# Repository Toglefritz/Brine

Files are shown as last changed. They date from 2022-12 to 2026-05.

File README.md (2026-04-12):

# Brine

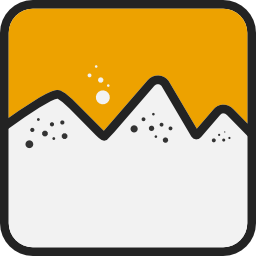
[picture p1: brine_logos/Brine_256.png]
Brine logo


# Hello :wave:

Do you ever forget to refill the salt in your water softener? Yes you do. It is probably a safe
bet to say that everybody who has a water softener in their home forgets to refill the salt from
time to time. That "time to time" might even be several months in row.

The Brine water softener monitor keeps track of the amount of salt remaining in your water softener
and delivers alerts when the level is low. With this tool, you can keep your water softener filled
with salt and working properly, which, in turn, will keep your appliances free of mineral deposits,
your hands and hair well-moisturized, your laundry machine effective, and spots off your dishes.

# Overview 

Brine is an IoT water softener monitor. It tracks the amount of salt remaining in a water softener
and delivers alerts when the level is low, keeping your appliances free of mineral deposits, your
hands and hair well-moisturized, your laundry machine effective, and spots off your dishes.

The project spans hardware, firmware, a mobile companion app, cloud backend services, and a
marketing website.

## Project Status

> **Hardware finalization and pre-manufacturing**
>
> The hardware design is being finalized ahead of final system integration.
> Preparation for first-run manufacturing is underway.

## How It Works

A Brine device mounts inside the lid of a water softener, facing down toward the salt. It uses a
VL53L1X distance sensor to measure the distance from the top of the softener to the salt surface,
then calculates an approximate percentage of salt remaining. The device wakes from deep sleep once
every 24 hours to take a measurement, report it to the cloud, and go back to sleep.

Users set up a Brine device through the companion mobile app using Bluetooth Low Energy. The app
walks through pairing, WiFi provisioning, and account association. Once provisioned, the app
displays a dashboard with salt level, battery level, and device information, and delivers push
notifications when levels are low.

## Repository Structure

| Directory | Description |
|---|---|
| [`brine_app`](brine_app/) | Flutter companion app for iOS, Android, and macOS. Handles device provisioning via BLE and displays device status on a dashboard. |
| [`brine_firmware`](brine_firmware/) | ESP32 firmware built with PlatformIO and the Arduino framework. Manages the distance sensor, battery monitoring, BLE communication, and deep sleep. |
| [`brine_cloud_functions`](brine_cloud_functions/) | Firebase Cloud Functions that form the backend infrastructure. Handles device registration, data ingestion, and push notifications. |
| [`brine_website`](brine_website/) | Flutter web marketing site for the Brine product. |
| [`brine_docs`](brine_docs/) | Project documentation covering OTA updates, power management, provisioning, and security. |
| [`brine_electronics`](brine_electronics/) | PCB designs, Gerber files, prototypes, and reference materials for the Brine hardware. |
| [`brine_cad`](brine_cad/) | 3D models and drawings for the device enclosure (Plasticity, STEP, and STL formats). |
| [`brine_logos`](brine_logos/) | Brand assets and logo files in various formats. |
| [`brine_store_listings`](brine_store_listings/) | App store listing assets including screenshots and feature graphics. |
| [`brine_dev_tui`](brine_dev_tui/) | Terminal UI launcher for starting development tools (firmware flashing, emulator, serial monitor, Flutter app, Firebase emulator). |

## Development Launcher

The project includes a terminal UI for launching the various tools needed during local development.
Instead of remembering individual commands across multiple directories, the launcher provides a
single interface to start everything from one place.

Double-click `brine_dev_tui/Brine Launcher.command` in Finder to build and run it, or from the
terminal:

```sh
cd brine_dev_tui
go build -o brine-launcher .
./brine-launcher
```

See [`brine_dev_tui/README.md`](brine_dev_tui/README.md) for controls and architecture details.

## Technology Overview

- **Firmware**: C++ on ESP32 via PlatformIO / Arduino framework
- **Mobile App**: Flutter (Dart), targeting iOS, Android, and macOS
- **Backend**: Firebase (Cloud Functions, Firestore, Authentication, Cloud Messaging)
- **Website**: Flutter Web, hosted on Firebase Hosting
- **Hardware**: Custom PCB with ESP32 and VL53L1X distance sensor, powered by rechargeable LiPo battery
- **CAD**: Plasticity for enclosure design

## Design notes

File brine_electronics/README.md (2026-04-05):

# Brine

PCB design and hardware reference for the Brine Monitor, an IoT device that monitors the amount of
salt remaining in a water softener.

## Hello :wave:

Do you ever forget to refill the salt in your water softener? Yes you do. It is probably a safe
bet to say that everybody who has a water softener in their home forgets to refill the salt from
time to time. That "time to time" might even be several months in row.

The Brine water softener monitor keeps track of the amount of salt remaining in your water softener
and delivers alerts when the level is low. With this tool, you can keep your water softener filled
with salt and working properly, which, in turn, will keep your appliances free of mineral deposits,
your hands and hair well-moisturized, your laundry machine effective, and spots off your dishes.

## Hardware Overview

The Brine device is a battery-powered sensor board built around a Seeed Studio XIAO ESP32-S3
module. It measures the distance from the top of a water softener to the salt surface using a
VL53L1X time-of-flight distance sensor, then reports that measurement to the cloud over WiFi.

The board includes:

- XIAO ESP32-S3 microcontroller module (WiFi, BLE, and GPIO)
- VL53L1X time-of-flight distance sensor connected over I2C
- Battery power input with a voltage divider for battery level monitoring
- A physical button for entering setup mode and waking from deep sleep
- An RGB LED for status indication during provisioning and operation

The PCB is a two-layer board designed to fit inside a custom enclosure. Enclosure models are
maintained separately in the [`brine_cad`](../brine_cad/) directory.

## KiCAD Project

The active design lives in the `Brine Mainboard/` directory and is a KiCAD 9 project.

### Hierarchical Schematic Structure

The schematic is organized as a set of hierarchical sheets. The root sheet (`Brine.kicad_sch`)
acts as a block diagram of the hardware, showing each functional block and the signals that
connect them. Each block is defined in its own schematic sheet with the full circuit detail for
that subsystem.

| Sheet | File | Description |
|---|---|---|
| Root | `Brine.kicad_sch` | Top-level block diagram showing all subsystems and their interconnections. |
| XIAO ESP32-S3 | `xiao_esp32-s3.kicad_sch` | Microcontroller module pinout and connections to all peripheral blocks. |
| Battery | `brine_battery.kicad_sch` | Battery input and power delivery. |
| Button | `brine_button.kicad_sch` | Physical pushbutton circuit for user interaction and wake-from-sleep. |
| RGB LED | `brine_rgb_led.kicad_sch` | Status LED driven by the microcontroller. |
| Battery Monitor | `brine_battery_monitor.kicad_sch` | Voltage divider circuit for reading battery level on an analog input. |
| Distance Sensor | `brine_distance_sensor.kicad_sch` | VL53L1X time-of-flight sensor with I2C and shutdown control lines. |

The root sheet is the best starting point for understanding how the subsystems relate to each
other. Open it in KiCAD's schematic editor to see the block-level signal flow, then navigate into
individual sheets for component-level detail.

### PCB Layout

The PCB (`Brine.kicad_pcb`) is a two-layer board. A 3D STEP model of the board (`Brine.step`) is
included for use in enclosure design and fit verification.

Production outputs, including Gerbers, BOM, and pick-and-place position files, are generated into
the `production/` subdirectory.

## Directory Structure

| Directory | Description |
|---|---|
| `Brine Mainboard/` | Active KiCAD project containing schematics, PCB layout, production outputs, and the board STEP model. |
| `Libraries/` | Custom KiCAD symbol and footprint libraries for components not available in the default KiCAD libraries (e.g., VL53L1X). |
| `Gerbers/` | Legacy Gerber output directory. Current production files are generated into `Brine Mainboard/production/`. |
| `Archive/` | Previous board revisions and design iterations, including earlier EAGLE-based designs. Kept for reference. |

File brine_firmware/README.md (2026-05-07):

# Brine Device Firmware

This repository contains the firmware for Brine, an IoT device that monitors the amount of salt remaining in a water softener.

# Hello :wave:

Do you ever forget to refill the salt in your water softener? Yes you do. It is probably a safe bet to say that everybody who has a water softener in their home forgets to refill the salt from time to time. That "time to time" might even be several months in row.

The Brine water softener monitor keeps track of the amount of salt remaining in your water softener and delivers alerts when the level is low. With this tool, you can keep your water softener filled with salt and working properly, which, in turn, will keep your appliances free of mineral deposits, your hands and hair well-moisturized, your laundry machine effective, and spots off your dishes.

## Hardware

The Brine device is built around the ESP32, a powerful, versatile microcontroller that provides the WiFi connectivity necessary for the IoT functionality of the device and BLE connectivity necessary for its setup process. The ESP32 was chosen for its combination of processing power, connectivity options, and power efficiency, which is crucial for a battery-powered device.

The primary sensor used by the Brine device is the VL53L1X distance sensor. This sensor measures the distance from the top of the water softener to the level of the salt within the appliance. By comparing this measurement to the known distance when the water softener is empty, the device can calculate an approximate percentage of salt remaining.

For user feedback, the device includes an LED. This LED can display different patterns to indicate the device's status. This system is mainly used during the provisioning process and the LED generally remains off during normal operation so its use does not affect the battery life of the device.

The device is powered by a rechargeable lithium polymer battery. To maximize battery life, the device spends most of its time in a deep sleep state. It wakes up once every 24 hours to measure the salt level, send the data to the backend services, and then returns to the deep sleep state. This power management strategy allows the device to operate for extended periods without requiring a battery change.

The device is designed to be mounted inside the lid of a water softener, facing down towards the salt. This positioning allows the distance sensor to accurately measure the salt level.

## Firmware

The firmware for the Brine device is written using PlatformIO, an open-source ecosystem for IoT development, in conjunction with Visual Studio Code, a powerful and versatile code editor. The Arduino framework is used due to its simplicity, robustness, and the vast amount of resources and libraries available.

The firmware follows a service-oriented architecture, encapsulating different pieces of functionality into their own modules. This design allows for a high degree of modularity and reusability, making the firmware easier to understand, maintain, and extend.

Each service in the firmware is responsible for a specific piece of functionality. For example, there might be a service for managing the distance sensor, another for handling communication with the backend services, and yet another for controlling the RGB LED.

The firmware also includes power management functionality to ensure the device spends most of its time in a deep sleep state, waking up only to perform measurements and communicate with the backend services. This approach maximizes battery life and ensures the device can operate for extended periods without requiring a battery change.

```mermaid
graph LR
    A[main.cpp] --> B[Button Service]
    A --> C[LED Service]
    A --> D[Distance Sensor Service]
    A --> F[Battery Monitor Service]
    B --> G[Button Hardware]
    C --> H[LED Hardware]
    D --> I[Distance Sensor Hardware]
    F --> K[Battery Monitor Hardware]
```

## Getting Started

To start working with the Brine device firmware, follow these steps:

### Setting Up the Development Environment
1. Install [Visual Studio Code](https://code.visualstudio.com/download).
2. Open Visual Studio Code and navigate to the Extensions view (View -> Extensions).
3. Search for and install the PlatformIO IDE extension.

### Adding Libraries
The Brine device firmware uses several libraries. To add them to your project:
1. Open the PlatformIO home page in Visual Studio Code (View -> PlatformIO).
2. Navigate to Libraries.
3. Search for and install the following libraries: (List the libraries used by the project)

### Connecting the Device
1. Connect the Brine device to your development machine using a USB cable.
2. In Visual Studio Code, open the PlatformIO home page.
3. Navigate to Devices to verify that the Brine device is recognized.

### Flashing Firmware
1. Open the Brine device firmware project in Visual Studio Code.
2. Build the project by clicking the checkmark icon in the PlatformIO toolbar.
3. Upload the firmware to the device by clicking the right arrow icon in the PlatformIO toolbar.

After following these steps, your Brine device should be running the latest firmware and ready for use.

## Commenting and Documentation

Doxygen-style comments are used throughout this project for code documentation. This allows for the automatic generation of documentation and ensures that the codebase is easy to understand and maintain.

The following guidelines regarding documentation should be followed while working on this project:

1.  Always document code as it is written. It is much easier to write comments while the code is fresh in your mind and you still have the context in which it was written.
2. Use Doxygen-style comments (`/** ... */` for multi-line comments, `///` for single-line comments).
3.  Document all public APIs. Include a brief description, detailed description, parameters, and return values.
4.  Use `@brief` for a brief description, `@details` for a detailed description, `@param` for parameters, and `@return` for return values.
5.  For classes and structures, document what they represent and how they should be used.
6.  For functions, document what they do, what the parameters are, what value they return, if any, and the purpose for which they were created.

Here is a generic Doxygen comment template for a function:

```
/**
 * @brief Brief description of the function
 * @details Detailed description of the function
 * 
 * @param paramName Description of the parameter
 * @return Description of the return value
 */
void functionName(Type paramName) {
    // function body
}
```

And for a class:

```
/**
 * @brief Brief description of the class
 * @details Detailed description of the class
 */
class ClassName {
    // class body
}
```

## Bluetooth Communication

Brine devices utilize Bluetooth communication for the provisioning process. This technology allows for seamless and efficient communication between client devices, such as the companion Brine mobile app, and Brine IoT devices.

All Brine devices use the same UUID (Universally Unique Identifier) for their primary services. This UUID is a unique string of characters that identifies the services provided by the Brine device. It can be used as a filter by client devices when performing a scan for nearby Brine devices. The UUID for Brine devices is as follows:

> 6272696E-6573-616C-746D-6F6E69746F72

In addition to the primary service UUID, Brine devices also use the same UUID values for their BLE (Bluetooth Low Energy) characteristics. These characteristics are attributes that define the behavior of the Brine device. The UUIDs for these characteristics allow client devices to identify and interact with the correct characteristics on the Brine device.

### Bluetooth API Overview

The Bluetooth API implemented in the IoT device firmware allows for communication with a central device (such as a Flutter app) using a JSON-based protocol. This section provides an overview of the structure of the API, including the format for commands and responses, and details how the firmware processes these communications.

### Command Structure

Commands are received from the central device and are represented as JSON objects. Each command must include a command field specifying the type of command being issued.

**Example Command**

To request the device ID from the IoT device, the following JSON command is sent:

```json
{
    "command": "get_device_id"
}
```

### Response Structure

Responses are sent from the IoT device to the central device in reply to commands. Each response is represented as a JSON object and includes a response field specifying the type of response.

**Success Responses**

A successful response to the get_device_id command will include the device ID:

```json
{
    "response": "device_id",
    "device_id": "vast_teal_elephant"
}
```

**Error Responses**

If an error occurs or an unknown command is received, an error response is sent:

```json
{
    "response": "error",
    "message": "Unknown command"
}
```

## PlatformIO CLI Commands

### Flashing Firmware

Build and upload firmware to the connected device:

```bash
pio run -e seeed_xiao_esp32c3 --target upload
```

Build without uploading (compile check only):

```bash
pio run -e seeed_xiao_esp32c3
```

### Running Tests

Run a specific test suite on hardware:

```bash
pio test -e seeed_xiao_esp32c3 --filter <test_name>
```

For example, to run the GPIO button test:

```bash
pio test -e seeed_xiao_esp32c3 --filter test_GPIOButton
```

Run all tests:

```bash
pio test -e seeed_xiao_esp32c3
```

### Serial Monitor

Open the serial monitor to view debug output:

```bash
pio device monitor
```

### Clean Build

Remove all build artifacts and force a full rebuild:

```bash
pio run -e seeed_xiao_esp32c3 --target clean
```

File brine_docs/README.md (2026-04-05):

# Brine

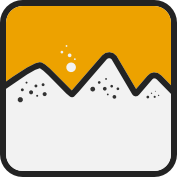
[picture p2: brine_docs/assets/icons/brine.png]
Brine logo


Documentation for the Brine Monitor, an IoT device that monitors the amount of salt remaining
in a water softener.

## Hello :wave:

Do you ever forget to refill the salt in your water softener? Yes you do. It is probably a safe
bet to say that everybody who has a water softener in their home forgets to refill the salt from
time to time. That "time to time" might even be several months in row.

The Brine water softener monitor keeps track of the amount of salt remaining in your water softener
and delivers alerts when the level is low. With this tool, you can keep your water softener filled
with salt and working properly, which, in turn, will keep your appliances free of mineral deposits,
your hands and hair well-moisturized, your laundry machine effective, and spots off your dishes.

## Table of Contents

1. [Power](power/)
    - [battery_monitoring](power/battery_monitoring.md): Describes the voltage divider circuit used to monitor the voltage of the AA batteries that power the Brine device, including resistor selection and safe input levels for the ESP32 analog pin.
    - [deep_sleep_handling](power/deep_sleep_handling.md): Explains how the Brine firmware uses the ESP32's deep sleep mode to conserve battery, including the 24-hour wake cycle, timer and GPIO wakeup sources, and the setup mode triggered by a physical button press.
2. [OTA](ota/)
    - [ota_architecture](ota/ota_architecture.md): Documents the architecture of the over-the-air firmware update system, covering the device, cloud, and mobile components, the update flow sequence, data formats, security layers, and deployment topology.
    - [ota_setup](ota/ota_setup.md): A setup guide for the OTA cloud infrastructure, including Firebase Cloud Function deployment, Firestore collection configuration, Storage rules, firmware version management, and testing procedures.
3. [Provisioning](provisioning/)
    - [provisioning_process](provisioning/provisioning_process.md): Walks through the full provisioning sequence for a new Brine device, from physical button activation and BLE pairing through device association, PSK transfer, WiFi credential exchange, hardware installation, and appliance height configuration.
4. [Security](security/)
    - [hmac_security](security/hmac_security.md): Explains the HMAC-based request signing mechanism used to authenticate data sent from Brine devices to the Firebase backend, including how PSKs are provisioned, how signatures are generated and verified, and how keys can be rotated or revoked.
5. [Cloud](cloud/)
    - [cloud_infrastructure](cloud/cloud_infrastructure.md): Describes the Firebase-based cloud backend, including the Firestore data model, the set of Cloud Functions exposed as HTTP endpoints, authentication and HMAC verification, push notifications, and local development with the Firebase Emulator Suite.

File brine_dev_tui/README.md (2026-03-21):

# Brine Launcher

A terminal UI for launching the development tools used in the Brine project. Instead of memorizing and manually running a collection of terminal commands, this tool provides a single interface to start and stop everything you need for local development.

Built with [Go](https://go.dev), [Bubbletea](https://github.com/charmbracelet/bubbletea), and [Lipgloss](https://github.com/charmbracelet/lipgloss).

## Why This Exists

The Brine project involves multiple systems that need to run simultaneously during development: device firmware, a device emulator, a serial monitor, the Flutter mobile app, and the Firebase emulator suite. Remembering the exact commands for each, and running them in the right order, is tedious and error-prone. This launcher centralizes all of that into a single, navigable interface.

## Available Tools

| Tool | Description |
|---|---|
| Flash Firmware | Build and flash firmware to the device |
| Device Emulator | Start the device emulator for local testing  |
| Serial Monitor | Open serial monitor for device output |
| Flutter App | Launch the Flutter mobile application |
| Firebase Emulator  | Start the Firebase local emulator suite |

## Usage

### Build and Run

```sh
cd brine_dev_tui
go build -o brine-launcher .
./brine-launcher
```

### Controls

| Key | Action |
|---|---|
| `↑` / `k` | Move cursor up |
| `↓` / `j` | Move cursor down |
| `Enter` / `Space` | Toggle selected tool (start/stop) |
| `q` / `Ctrl+C` | Quit |

## Architecture

The application follows the [Elm Architecture](https://guide.elm-lang.org/architecture/) via Bubbletea, which separates concerns into model, update, and view.

```
brine_dev_tui/
├── main.go      Entry point. Initializes and runs the Bubbletea program.
├── model.go     Application state and input handling (Update loop).
├── view.go      Renders the interface from current state (View function).
├── tool.go      Tool type definition and the default tool list.
├── styles.go    All Lipgloss visual styles and color palette.
├── go.mod       Go module and dependencies.
└── go.sum       Dependency checksums.
```

## Dependencies

- [Bubbletea](https://github.com/charmbracelet/bubbletea) — Terminal UI framework based on the Elm Architecture.
- [Lipgloss](https://github.com/charmbracelet/lipgloss) — Styling and layout for terminal rendering.

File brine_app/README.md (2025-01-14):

# Brine

Brine logo

The companion app for the Brine Monitor, an IoT device that monitors the amount of salt remaining
in a water softener.



# Hello :wave:

Do you ever forget to refill the salt in your water softener? Yes you do. It is probably a safe
bet to say that everybody who has a water softener in their home forgets to refill the salt from
time to time. That "time to time" might even be several months in row.

The Brine water softener monitor keeps track of the amount of salt remaining in your water softener
and delivers alerts when the level is low. With this tool, you can keep your water softener filled
with salt and working properly, which, in turn, will keep your appliances free of mineral deposits,
your hands and hair well-moisturized, your laundry machine effective, and spots off your dishes.

# Application Flow

The application has two main workflows. First, the app implements a provisioning process used to
add a Brine device to the user's account. This process consists of communicating with a target
Brine device via Bluetooth Low Energy, connecting that device to a WiFi network, and performing an
API call necessary to associate the Brine device to the user's account.

Second, the app displays information about one or more Brine devices on a user's account on a
"dashboard" screen, which includes the most recently reported salt and battery level for the
device, as well as information about the device itself. The app will facilitate the delivery
of push notifications when the battery and/or salt level on one of the Brine devices for a user
are low.

## Provisioning Flow

The diagram below shows the provisioning flow for a Brine device.

> Some details in this flow are still being implemented and may change over time.

```mermaid
sequenceDiagram
    participant User
    participant MobileApp
    participant BrineDevice
    participant Backend

    User ->> BrineDevice: Press button to initiate device activation
    BrineDevice ->> MobileApp: Start BLE advertising
    MobileApp ->> MobileApp: Scan for BLE devices
    MobileApp ->> BrineDevice: Discover Brine device
    MobileApp ->> BrineDevice: Perform BLE pairing and bonding
    MobileApp ->> BrineDevice: Retrieve device ID
    MobileApp ->> Backend: Send device ID and user ID
    Backend ->> Backend: Associate device with user account
    MobileApp ->> Backend: Request PSK for the Brine device
    Backend ->> MobileApp: Generate and return PSK
    MobileApp ->> BrineDevice: Transfer PSK
    BrineDevice ->> BrineDevice: Save PSK to NVS
    MobileApp ->> BrineDevice: Request WiFi scan results
    BrineDevice ->> BrineDevice: Perform WiFi scan
    BrineDevice ->> MobileApp: Return list of WiFi networks
    User ->> MobileApp: Select WiFi network
    User ->> MobileApp: Provide WiFi credentials
    MobileApp ->> BrineDevice: Send WiFi credentials over BLE
    BrineDevice ->> BrineDevice: Connect to WiFi network
    BrineDevice ->> MobileApp: Report WiFi connection success
    MobileApp ->> User: Notify provisioning completion
```

# Bluetooth API Overview

The Bluetooth API enables communication between the Flutter app and the IoT device using a
JSON-based protocol. This section provides an overview of the structure of the API, including the
format for commands and responses

## Command Structure

Commands are sent from the central device (e.g., a Flutter app) to the IoT peripheral device. Each
command is represented as a JSON object with a command field specifying the type of command.

**Example Command**:

To request the device ID from the IoT device, the following JSON command is used:

```json
{
    "command": "get_device_id"
}
```

## Response Structure

Responses are sent from the IoT peripheral device to the central device in reply to commands. Each response is represented as a JSON object with a response field specifying the type of response.

**Success Responses**

For example, a successful response to the get_device_id command will include the device ID:

```json
{
    "response": "device_id",
    "device_id": "Brine-1234"
}
```

**Error Responses**

If an error occurs or an unknown command is received, an error response is sent:

```json
{
    "response": "error",
    "message": "Unknown command"
}
```

# Firebase Local Emulator Notes

Development can be done against the Firebase local emulator rather than the live Firebase
environment in order to prevent interference with the production environment and to provide a
safe environment for development without billing.

Start the Firebase emulator with the command, `firebase emulators:start`.

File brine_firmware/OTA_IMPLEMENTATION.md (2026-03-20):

# Brine OTA (Over-The-Air) Firmware Update System

## Overview

The Brine device supports Over-The-Air (OTA) firmware updates through two methods:
1. **Cloud-based updates** (Primary method) - Firmware is downloaded from Firebase Storage via WiFi
2. **Bluetooth-based updates** (Backup method) - Firmware is transferred via BLE (future enhancement)

## Architecture

### Cloud Components

#### Firebase Cloud Function: `checkFirmwareUpdate`
- **Endpoint**: `/checkFirmwareUpdate`
- **Method**: POST
- **Purpose**: Checks if a newer firmware version is available for a device

**Request Body**:
```json
{
  "device_id": "device-123",
  "current_version": "1.0.0"
}
```

**Response (Update Available)**:
```json
{
  "update_available": true,
  "latest_version": "1.1.0",
  "download_url": "https://storage.googleapis.com/...",
  "release_notes": "Bug fixes and improvements"
}
```

**Response (No Update)**:
```json
{
  "update_available": false,
  "message": "Current version is up to date.",
  "current_version": "1.0.0",
  "latest_version": "1.0.0"
}
```

#### Firestore Collection: `firmware_versions`

Each firmware version document contains:
```javascript
{
  version: "1.1.0",              // Semantic version string
  version_number: 110,           // Numeric version for sorting (major*100 + minor*10 + patch)
  download_url: "https://...",   // Firebase Storage URL for firmware binary
  release_notes: "...",          // Optional release notes
  active: true,                  // Whether this version should be offered to devices
  created_at: "2025-11-27T...",  // Timestamp
  file_size: 1234567,            // Size in bytes
  checksum: "sha256:..."         // Optional checksum for verification
}
```

### Firmware Components

#### OTAService Class
Located in `lib/OTAService/`

**Key Methods**:
- `checkForUpdate(String &latestVersion, String &downloadUrl)` - Queries cloud for updates
- `performCloudUpdate(const String &downloadUrl)` - Downloads and applies firmware
- `beginBluetoothUpdate(size_t firmwareSize)` - Prepares for BLE update
- `writeBluetoothChunk(const uint8_t *data, size_t len)` - Writes BLE data chunk
- `endBluetoothUpdate()` - Finalizes BLE update
- `getCurrentVersion()` - Returns current firmware version
- `abortUpdate()` - Cancels an in-progress update

#### Firmware Version
Defined in `include/OTAService.h`:
```cpp
#define FIRMWARE_VERSION "1.0.0"
```

**Important**: Update this version string with each firmware release.

## Update Workflow

### Cloud Update Process

1. **Device Wake-Up**
   - Device wakes from deep sleep (timer or button press)
   - Connects to WiFi using saved credentials
   - Calls `_checkAndPerformOTAUpdate()`

2. **Update Check**
   - Device sends current version to `checkFirmwareUpdate` endpoint
   - Cloud function queries Firestore for latest active firmware
   - Compares versions using semantic versioning

3. **Update Download & Installation**
   - If update available, device downloads firmware binary
   - ESP32 Update library writes to OTA partition
   - Progress is logged every 10%
   - LED indicates update in progress

4. **Verification & Reboot**
   - Firmware is verified
   - Device reboots into new firmware
   - On next wake, device reports new version

### Update Trigger Points

The device checks for updates at two key moments:

1. **Periodic Wake-Up** (Primary)
   - Device wakes from deep sleep to take measurements
   - Checks for updates before uploading sensor data
   - Ensures devices stay updated during normal operation

2. **Provisioning Start** (Secondary)
   - When user presses button to enter provisioning mode
   - Checks for updates before starting BLE advertising
   - Allows updates even if device is not regularly waking

## Deploying Firmware Updates

### Step 1: Build New Firmware

```bash
cd brine_firmware
# Update FIRMWARE_VERSION in include/OTAService.h
pio run -e seeed_xiao_esp32s3
```

The compiled binary will be at:
`.pio/build/seeed_xiao_esp32s3/firmware.bin`

### Step 2: Upload to Firebase Storage

```bash
# Upload to Firebase Storage
firebase storage:upload .pio/build/seeed_xiao_esp32s3/firmware.bin \
  --path firmware/brine-firmware-1.1.0.bin

# Get the download URL
firebase storage:get-url firmware/brine-firmware-1.1.0.bin
```

### Step 3: Create Firestore Document

Add a document to the `firmware_versions` collection:

```javascript
{
  version: "1.1.0",
  version_number: 110,  // 1*100 + 1*10 + 0
  download_url: "https://firebasestorage.googleapis.com/...",
  release_notes: "Bug fixes and performance improvements",
  active: true,
  created_at: new Date().toISOString(),
  file_size: 987654
}
```

### Step 4: Monitor Rollout

- Check device documents for `last_update_check` and `available_firmware_version` fields
- Monitor Cloud Function logs for update requests
- Devices will update on their next wake cycle

### Step 5: Rollback (if needed)

To rollback a problematic update:
1. Set the problematic version's `active` field to `false`
2. Ensure the previous stable version has `active: true`
3. Devices will receive the stable version on next check

## Bluetooth OTA (Future Enhancement)

The OTAService class includes methods for Bluetooth-based updates, designed for scenarios where:
- Device cannot connect to WiFi
- User needs to update device manually
- Emergency updates are required

### Planned BLE Update Flow

1. User initiates update from mobile app
2. App transfers firmware binary in chunks via BLE
3. Device writes chunks to OTA partition
4. After complete transfer, device verifies and reboots

### Implementation Considerations

- **Chunk Size**: Recommend 512 bytes per BLE packet
- **Progress Tracking**: App should display progress to user
- **Error Handling**: Support resume/retry on connection loss
- **Security**: Consider encrypting firmware during transfer
- **BLE Characteristics**: 
  - Control characteristic for commands (start, abort, finalize)
  - Data characteristic for firmware chunks
  - Status characteristic for progress updates

## Security Considerations

### Current Implementation
- Firmware downloads use HTTPS in production
- Firebase Storage URLs include authentication tokens
- Version comparison prevents downgrade attacks

### Future Enhancements
- Add firmware signature verification
- Implement checksum validation
- Add device authentication to update endpoint
- Consider encrypted firmware binaries
- Add rollback protection

## Testing

### Local Testing with Emulator

1. Start Firebase emulator:
```bash
cd brine_cloud_functions
firebase emulators:start
```

2. Build firmware with dev configuration:
```bash
cd brine_firmware
pio run -e seeed_xiao_esp32s3 -t upload
```

3. Monitor serial output:
```bash
pio device monitor
```

### Testing Update Flow

1. Create test firmware version in Firestore emulator
2. Trigger device wake-up (button press or wait for timer)
3. Observe update check in serial monitor
4. Verify firmware download and installation

### Unit Tests

Cloud function tests are in:
`brine_cloud_functions/functions/test/checkFirmwareUpdate.test.cjs`

Run tests:
```bash
cd brine_cloud_functions/functions
npm test
```

## Troubleshooting

### Device Not Checking for Updates
- Verify WiFi connection is successful
- Check Firebase endpoint URL in OTAService.cpp
- Ensure FLAVOR is correctly set in platformio.ini

### Update Check Fails
- Verify `firmware_versions` collection exists
- Check Cloud Function logs for errors
- Ensure device can reach Firebase endpoints

### Update Download Fails
- Verify download URL is accessible
- Check device has sufficient free space
- Ensure stable WiFi connection during download

### Device Doesn't Reboot After Update
- Check serial logs for Update.end() errors
- Verify firmware binary is valid
- Ensure partition table supports OTA

## Configuration

### Development vs Production

Set in `platformio.ini`:
```ini
build_flags = 
    -D FLAVOR=1  # Development (emulator)
    # or
    -D FLAVOR=2  # Production (live Firebase)
```

### Endpoints

**Development**:
- `http://192.168.86.39:5001/brine-3b212/us-central1/checkFirmwareUpdate`

**Production**:
- `https://checkfirmwareupdate-7wo3szegoq-uc.a.run.app`

Update the IP address in `OTAService.cpp` if your emulator runs on a different machine.

## Monitoring & Analytics

### Device-Level Tracking

Each device document tracks:
- `last_update_check`: Timestamp of last update check
- `available_firmware_version`: Latest version available to device
- `current_firmware_version`: Currently running version (future)

### Recommended Metrics

- Update check frequency
- Update success/failure rates
- Time to update across fleet
- Version distribution across devices
- Update-related errors

## Best Practices

1. **Version Numbering**: Use semantic versioning (major.minor.patch)
2. **Testing**: Test updates thoroughly before marking as active
3. **Gradual Rollout**: Consider phased rollouts for major updates
4. **Rollback Plan**: Always have a stable version ready to rollback to
5. **Release Notes**: Document changes for debugging and support
6. **Size Optimization**: Keep firmware size minimal to reduce download time
7. **Battery Awareness**: Updates consume significant power; ensure adequate battery

## Future Improvements

- [ ] Implement Bluetooth OTA updates
- [ ] Add firmware signature verification
- [ ] Support delta updates (only changed portions)
- [ ] Add update scheduling (specific time windows)
- [ ] Implement A/B partition updates for safer rollback
- [ ] Add update progress reporting to cloud
- [ ] Support forced updates for critical security patches
- [ ] Add update analytics dashboard
- [ ] Implement device grouping for staged rollouts
- [ ] Add automatic rollback on boot failure

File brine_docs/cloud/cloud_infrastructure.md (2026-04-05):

# Cloud Infrastructure

The Brine cloud backend runs on Firebase and is implemented as a set of HTTP Cloud Functions backed by Firestore. The source lives in the `brine_cloud_functions` directory. All functions are written in Node.js (CommonJS) and deployed through the Firebase CLI.

## Firebase Services

The backend relies on four Firebase services:

- Firebase Authentication, for verifying user identity on requests from the mobile app.
- Cloud Functions, for hosting the HTTP endpoints that the mobile app and the Brine device call.
- Firestore, for storing user accounts, device records, firmware metadata, push notification tokens, and sales leads.
- Firebase Cloud Messaging (FCM), for delivering push notifications to users when salt or battery levels are low.
- Firebase Storage, for hosting firmware binaries that devices download during OTA updates.

## Authentication

Most endpoints require a Firebase ID token in the `Authorization` header. An authentication middleware (`authMiddleware.cjs`) extracts and verifies this token before the request reaches the function handler. If the token includes a `userId` field, the middleware also confirms that it matches the UID encoded in the token.

Two authentication modes exist:

- `authenticate`: Verifies a standard Firebase Auth ID token. Used by all mobile app endpoints.
- `authenticateAnonymous`: Verifies a token from an anonymous Firebase Auth session. Used by the lead capture endpoint on the Brine website.

When running against the Firebase Emulator Suite, the middleware skips token verification and accepts a `x-user-id` header instead, allowing local testing without real credentials.

Two endpoints bypass Firebase Auth entirely and are open to unauthenticated callers:

- `updateDeviceLevels`: Called by the Brine hardware device. Authenticated via HMAC signature instead (see the [HMAC security documentation](../security/hmac_security.md)).
- `checkFirmwareUpdate`: Called by the Brine hardware device to check for OTA updates.

## Firestore Collections

### users

Each document is keyed by the user's Firebase Auth UID and contains:

- `uid`: The user's Firebase Auth UID.
- `devices`: An array of device IDs associated with the account.
- `fcm_tokens`: An array of FCM tokens registered for push notifications.

### devices

Each document is keyed by the device's unique identifier (e.g., `vast_teal_elephant`) and contains:

- `device_id`: The device identifier.
- `name`: A short human-readable name for the device.
- `battery_level`: The most recent battery reading (0 to 1 scale, or -1 if unknown).
- `salt_distance`: The most recent distance measurement from the sensor to the salt surface, in millimeters (-1 if unknown).
- `appliance_height`: The total interior height of the water softener, in millimeters (-1 if unknown).
- `last_updated`: ISO timestamp of the most recent level update.
- `psk`: The HMAC pre-shared key for this device.
- `psk_created_at`: ISO timestamp of when the PSK was generated.
- `psk_valid`: Whether the PSK is currently valid.
- `last_update_check`: ISO timestamp of the most recent OTA update check (written by `checkFirmwareUpdate`).
- `available_firmware_version`: The latest firmware version available at the time of the last update check.

### firmware_versions

Stores metadata for each published firmware release. Used by the `checkFirmwareUpdate` function. Each document contains:

- `version`: Semantic version string (e.g., `"1.1.0"`).
- `version_number`: Numeric representation for sorting (e.g., `110`).
- `download_url`: Firebase Storage URL for the firmware binary.
- `release_notes`: Optional description of changes.
- `active`: Boolean flag that controls whether devices are offered this version.
- `created_at`: ISO timestamp.
- `file_size`: Size of the binary in bytes.

### leads

Stores sales leads submitted through the Brine website. Each document contains a name, email, and timestamp.

## Cloud Functions

The table below lists each deployed function, who calls it, and what it does.

| Function | Caller | Auth | Purpose |
|---|---|---|---|
| `createUserDocument` | Mobile app | Firebase Auth | Creates a user document in Firestore after account creation. |
| `addDeviceToUser` | Mobile app | Firebase Auth | Links a device to the user's account and creates the device record if it does not exist. |
| `getUserDevices` | Mobile app | Firebase Auth | Returns the full device documents for all devices on the user's account. |
| `getDevice` | Mobile app | Firebase Auth | Returns a single device document after verifying the user has access to it. |
| `generatePSK` | Mobile app | Firebase Auth | Generates a random 32-byte pre-shared key, stores it on the device document, and returns it to the app for transfer to the hardware over BLE. |
| `updateApplianceHeight` | Mobile app | Firebase Auth | Updates the appliance height on a device document after verifying user access. |
| `removeDeviceFromUser` | Mobile app | Firebase Auth | Removes a device from the user's device list. Deletes the device record if no other users reference it. |
| `addFcmToken` | Mobile app | Firebase Auth | Registers an FCM push notification token on the user's document. |
| `deleteUser` | Mobile app | Firebase Auth | Deletes the user's Firestore document. |
| `updateDeviceLevels` | Brine device | HMAC | Accepts battery and salt distance readings from the hardware, updates the device document, and triggers a push notification if either level is critically low (below 5%). |
| `checkFirmwareUpdate` | Brine device | None | Compares the device's reported firmware version against the latest active version in Firestore and returns a download URL if an update is available. |
| `addLead` | Brine website | Anonymous Auth | Stores a sales lead (name and email) submitted through the website. |

## Push Notifications

When `updateDeviceLevels` receives a reading where the battery level is below 5% or the calculated salt level percentage is below 5%, it looks up the user who owns the device, retrieves their FCM tokens, and sends a push notification through Firebase Cloud Messaging. The notification message identifies which condition triggered the alert.

## Local Development

The project is configured to run against the Firebase Emulator Suite. The `firebase.json` file defines emulators for Auth (port 9099), Functions (port 5001), Firestore (port 8080), and Hosting (port 5000), all bound to `0.0.0.0` so they are accessible from other devices on the local network. A convenience script (`firebase_emulator_suite.command`) starts the emulator suite.

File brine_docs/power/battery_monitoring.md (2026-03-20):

# Battery Voltage Monitoring

A voltage divider circuit allows the ESP32 to monitor the voltage of the AA batteries that power brine via an analog input pin (A0/D0 in this case). An important consideration for the circuit is ensuring that the maximum voltage from the batteries when fully charged does not exceed the maximum input voltage of the GPIO pin. For the ESP32, the maximum input voltage for an analog pin is typically 3.3V. Since three AA batteries can provide a voltage slightly above 4.5V when fully charged (and even higher if they're new alkaline batteries, up to about 1.6V each or 4.8V total), the voltage divider needs to step down the voltage to a safe level for the ESP32 to read.

## Voltage Divider Basics

A voltage divider is a simple circuit made from two resistors in series across a voltage source. The output voltage is taken from the junction of the two resistors. The formula to calculate the output voltage ($V_{out}$) is given by the equation:

$V_{out} = V_{in} \times \frac{R_2}{R_1 + R_2}$

where:
- $V_{in}$ is the input voltage (the voltage of the batteries),
- $R_1$ is the resistance of the first resistor,
- $R_2$ is the resistance of the second resistor connected to ground.

## Designing the Voltage Divider

To ensure the voltage does not exceed 3.3V when the batteries are fully charged (assuming a max of 4.8V to provide some margin), appropriate values for $R_1$ and $R_2$ can be chosen using the formula above.

First, let's choose $R_2$ to be 10kΩ (a common value for such tasks) and solve for $R_1$ to achieve a maximum $V_{out}$ of 3.3V when $V_{in}$ is 4.8V.

Rearranging the formula to solve for $R_1$ we get:

$R_1 = R_2 \times (\frac{V_{in}}{V_{out}} - 1)$

Plugging in the values:

- $V_{in}$ = 4.8V (max battery voltage)
- $V_{out}$ = 3.3V (max GPIO pin voltage)
- $R_2$ = 10kΩ,

we can calculate $R_1$.

```
# Constants
V_in = 4.8  # Maximum input voltage from the batteries
V_out = 3.3  # Desired output voltage to the GPIO pin
R2 = 10_000  # Resistance of R2 in ohms (Ω)

# Calculating R1
R1 = R2 * ((V_in / V_out) - 1)
R1 = 4545.454545454546

```

The calculated value for $R_1$ is approximately 4545.45Ω. Since resistors come in standard values, you would typically round this to the nearest standard resistor value. The closest standard values are 4.7kΩ or 4.3kΩ. Choosing 4.7kΩ for $R_1$
would be safer as it ensures the maximum voltage seen by the GPIO pin does not exceed 3.3V, even if the batteries are slightly above 4.8V when fully charged.

## Final Design

- $R_1$ = 4.7kΩ
- $R_2$ = 10kΩ

This configuration will step down the voltage from the batteries to a safe level for the ESP32 to monitor via its A0/D0 pin.

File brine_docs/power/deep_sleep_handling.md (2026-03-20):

# Deep Sleep Handling

The Brine monitor is an IoT device designed to monitor the salt level in a water softener and communicate this information to a connected application. A crucial aspect of its design is the efficient use of battery power, achieved through the implementation of deep sleep functionality. This document outlines how the firmware manages deep sleep to extend battery life.

## Overview

Under normal operation, the Brine monitor enters a deep sleep state for 24 hours. Upon waking, it performs the following sequence of operations:

1. Measures the salt level using a time-of-flight distance sensor.
2. Connects to WiFi using pre-configured credentials obtained from the provisioning process.
3. Sends the measured salt level and battery level information to Firebase.
4. Re-enters deep sleep for another 24-hour cycle.

Additionally, the device supports a setup mode activated by pressing a physical button. This mode lasts for three minutes, allowing for device provisioning before returning to the normal operation cycle.

## Deep Sleep Configuration

### Sleep Duration

The firmware defines a sleep duration of 24 hours (86400 seconds) using the TIME_TO_SLEEP constant. This value is adjustable and is crucial for balancing measurement frequency with battery conservation.

### Wakeup Sources

The ESP32's deep sleep capabilities are utilized to reduce power consumption to a minimum. Wakeup from deep sleep is configured to occur through two primary sources:

- **Timer Wakeup**: After the defined sleep duration elapses, the ESP32 automatically wakes up to perform its operations.
- **GPIO Wakeup**: Pressing the setup button triggers a wakeup event, allowing the device to enter setup mode for provisioning.

## Deep Sleep Implementation

### Entering Deep Sleep

Upon completing its tasks (measurement, data transmission), the device prepares to enter deep sleep:

1. **GPIO Wakeup Configuration**: The firmware configures the GPIO pin connected to the setup button as a wakeup source. This setup ensures the device can exit sleep mode if the button is pressed.
2. **Timer Wakeup Configuration**: The sleep duration is set, taking into account whether the device is in debug mode. In debug mode, a shorter sleep duration (10 seconds) is used for testing purposes.
3. **Execution of Deep Sleep**: The device enters deep sleep mode, significantly reducing power consumption.

### Wakeup Handling

Upon waking from deep sleep, the device checks the wakeup source:

- **Timer Wakeup**: The device proceeds with its measurement and data transmission tasks before re-entering deep sleep.
- **GPIO Wakeup (Button Press)**: The device enters setup mode, indicated by the activation of the NeoPixel LED and the availability for provisioning. After three minutes or upon completion of provisioning, the device resumes normal operation.

## Debug Mode

The firmware includes a debug mode (`DEBUG` flag) that facilitates testing and troubleshooting:

- **Serial Output**: When enabled, debug messages are printed to the serial console to provide insights into the device's operation and wakeup reasons.
- **Reduced Sleep Duration**: For rapid testing, the sleep duration is significantly reduced in debug mode.

## Conclusion

The Brine monitor's firmware efficiently manages deep sleep to extend battery life while ensuring regular measurements and connectivity. By leveraging the ESP32's deep sleep features, the device maintains a balance between operational functionality and power conservation, making it an effective solution for monitoring water softener salt levels in an IoT context.

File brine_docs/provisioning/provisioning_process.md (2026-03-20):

# Provisioning Process for Brine IoT Devices

## Introduction

This document outlines the provisioning process for Brine IoT devices. The process involves interaction between the physical Brine device, a mobile app, and a Firebase backend service.

## Process Overview

1. **Device Activation**: The user initiates the process by pressing a button on the physical Brine device.
2. **BLE Advertising**: The Brine device begins advertising information over Bluetooth Low Energy (BLE).
3. **Device Discovery**: The mobile app scans for Brine devices over BLE and finds the advertising Brine device.
4. **BLE Pairing and Bonding**: The mobile app performs BLE pairing and bonding with the selected Brine device.
5. **Device Information Retrieval**: The mobile app obtains the Brine device's unique device ID. The app also obtains some information from the Brine device as a Bluetooth peripheral.
6. **Backend Communication**: The mobile app sends the device ID and device name, along with the authenticated user's credentials, to a Firebase backend service via a REST API endpoint that associates the Brine device to the user's account.
7. **Device Association**: The Firebase backend service associates the Brine device with the user's account.
8. **PSK Generation and Transfer**: The mobile app requests a PSK from the Firebasse backend and then transfers it to the Brine device.
8. **WiFi Credentials Transfer**: The mobile app collects WiFi credentials from the user and sends them to the Brine device over BLE.
9. **WiFi Connection**: The Brine device attempts to connect to the WiFi network using the provided credentials and reports the success of this operation back to the mobile app over BLE.
10. **Brine Installation**: The user is provided with instructions to install the Brine device in the water softener.
11. **Set Appliance Height**: The user measures the height of their water softener and inputs this measurement into the app. The app sends this height to the the cloud backend. 
12. **Provisioning Completion**: The Brine device and the mobile app exchange a final message to confirm to each other that the provisioning process is complete.

```mermaid
sequenceDiagram
    participant User
    participant MobileApp
    participant BrineDevice
    participant Backend

    User ->> BrineDevice: Press button to initiate device activation
    BrineDevice ->> MobileApp: Start BLE advertising
    MobileApp ->> MobileApp: Scan for BLE devices
    MobileApp ->> BrineDevice: Discover Brine device
    MobileApp ->> BrineDevice: Perform BLE pairing and bonding
    MobileApp ->> BrineDevice: Retrieve device ID
    MobileApp ->> Backend: Send device ID and user ID
    Backend ->> Backend: Associate device with user account
    MobileApp ->> Backend: Request PSK for the Brine device
    Backend ->> MobileApp: Generate and return PSK
    MobileApp ->> BrineDevice: Transfer PSK
    BrineDevice ->> BrineDevice: Save PSK to NVS
    MobileApp ->> BrineDevice: Request WiFi scan results
    BrineDevice ->> BrineDevice: Perform WiFi scan
    BrineDevice ->> MobileApp: Return list of WiFi networks
    User ->> MobileApp: Select WiFi network
    User ->> MobileApp: Provide WiFi credentials
    MobileApp ->> BrineDevice: Send WiFi credentials over BLE
    BrineDevice ->> BrineDevice: Connect to WiFi network
    BrineDevice ->> MobileApp: Report WiFi connection success
    MobileApp ->> User: Notify provisioning completion
```

## Detailed Steps

### Device Activation

The device activation step is the first step in the provisioning process. It involves the user pressing a button on the physical Brine device to initiate the process. This button press serves as a proof of possession check, ensuring that the user attempting to provision the Brine device has physical access to it.

Once the button is pressed, the Brine device starts advertising information over Bluetooth Low Energy (BLE). This enables the mobile app to discover and connect to the Brine device. The device will continue to advertise and accept incoming connections for a period of three minutes after the button is pressed.

During this time, the mobile app scans for Brine devices over BLE.

### Device Discovery

The device discovery step involves the mobile app scanning for nearby Brine devices over Bluetooth Low Energy (BLE). This is done by performing a BLE scan and filtering the results based on the primary service UUID used by all Brine devices.

### Device Selection

In most cases, only a single Brine device is expected to be discovered over Bluetooth Low Energy (BLE). In this scenario, the mobile app will automatically continue to the next step without user intervention.

However, there may be situations where multiple Brine devices are detected during the scan. In such cases, the mobile app will present a list of available devices to the user. The user can then choose the specific Brine device they wish to provision from the list.

This user selection ensures that the provisioning process is performed on the intended Brine device and avoids any potential confusion or errors that may arise from provisioning the wrong device.

Once the user selects the desired Brine device, the mobile app proceeds to the next step in the provisioning process.

### BLE Pairing and Bonding

The BLE pairing and bonding step is crucial for ensuring a secure provisioning process. During this step, the mobile app establishes a secure connection with the selected Brine device by performing BLE pairing and bonding.

One important aspect of this step is the use of encrypted BLE characteristics for sharing sensitive information, such as WiFi credentials. As mentioned earlier, WiFi credentials are shared between the mobile app and the Brine device during the provisioning process. These credentials contain sensitive information that, if intercepted, could compromise the security of the WiFi network.

By using encrypted BLE characteristics, the risk of interception and compromise of WiFi credentials is minimized. Encrypted characteristics ensure that the messages exchanged between the mobile app and the Brine device are protected and cannot be easily deciphered by unauthorized parties.

To achieve this, both the mobile app and the Brine device must support the necessary encryption algorithms and key exchange protocols. The mobile app initiates the pairing process by sending a pairing request to the Brine device. The Brine device responds with a pairing response, and both devices exchange encryption keys to establish a secure connection.

Once the secure connection is established, the mobile app can safely share the WiFi credentials with the Brine device over the encrypted BLE characteristics. This ensures that even if the messages are intercepted, they cannot be easily decrypted without the encryption keys.

Using encrypted BLE characteristics for sharing WiFi credentials adds an extra layer of security to the provisioning process, protecting sensitive information from unauthorized access. It is important to ensure that both the mobile app and the Brine device are properly configured to support encryption and that the encryption keys are securely exchanged during the pairing and bonding process.

### Device Association

The device association step is where information about the Brine device and the authenticated user is linked in backend resources. This association enables the mobile app to retrieve a list of Brine devices associated with the user and display relevant information from those devices.

To perform the device association, the mobile app sends the retrieved device ID, device name, and the authenticated user's credentials to a Firebase backend service via a REST API endpoint.

The Firebase backend service receives the device information and user ID and associates the Brine device with the user's account. This association is typically stored in a database or other backend resource, allowing the mobile app to query and retrieve the associated devices when needed.

By associating the Brine device with the user's account, the mobile app can provide a personalized experience for the user. On future launches of the mobile app, it can retrieve the list of associated Brine devices from the backend and display relevant information from those devices, such as device status, sensor readings, or other device-specific data.

###  WiFi Credentials Transfer

After the Brine device is associated with the user’s account, the mobile app prompts the user to enter the WiFi credentials (SSID and password) of the network to which the Brine device should connect.

Once the user has entered the WiFi credentials, the mobile app proceeds to send these credentials to the Brine device over Bluetooth Low Energy (BLE).

After sending the WiFi credentials, the mobile app waits for a response from the Brine device to confirm the receipt and processing of the credentials. 

### Brine Installation

The mobile app provides the user with step-by-step instructions for installing the Brine monitor in the water softener.

1. **Prepare the Water Softener**: Ensure that the water softener is clean and free of any debris that might interfere with the installation of the Brine monitor.
2. **Position the Brine Monitor**: Place the Brine monitor on top of the water softener, ensuring that it is centered and stable.
3. **Secure the Monitor**: Use the provided mounting hardware to secure the Brine monitor in place. Follow the specific instructions for your water softener model to ensure a proper fit.

Once the installation is verified, the Brine monitor will begin measuring the salt level in the water softener and transmitting this data to the cloud backend for analysis and monitoring.

### Set Appliance Height

After the Brine device is connected to the user's account, the mobile app prompts the user to measure the height of the water softener. The user is instructed to use a measuring tape to determine the distance from the base to the top of the water softener.

Once the user has measured the height, they enter this value into the mobile app. The app then sends this height information to the cloud backend and uses it to calculate the approximate percentage of salt left in the water softener. This calculation is based on the distance between the top of the water softener and the current level of salt inside it, which is measured by the Brine device.

The steps are as follows:

1. The mobile app prompts the user to measure the height of the water softener.
2. The user measures the height using a measuring tape.
3. The user enters the measured height into the mobile app.
4. The app sends this information to the cloud backend via a REST API request.
5. The Brine device measures the distance from the top of the water softener to the salt level.
6. The app uses the height and distance measurements to estimate the percentage of salt remaining in the water softener.

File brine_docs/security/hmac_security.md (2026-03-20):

# HMAC-Based Security in Brine Devices

## Introduction

In all aspects of Brine’s design, from the mobile app, to the Firebase backend, to the physical Brine hardware and the firmware running on it, security is of critical importance. A key component of IoT security is ensuring the authenticity and integrity of the data transmitted between devices and backend services. This is particularly challenging in IoT environments, where devices operate in potentially hostile networks.

Brine devices implement a robust security mechanism based on HMAC (Hash-based Message Authentication Code) signatures. This mechanism ensures that only authorized devices can send data to the backend by enabling the Firebase backend to verify the authenticity of incoming requests. Unlike more complex cryptographic systems that require public-private key pairs and cryptographic coprocessors, HMAC-based security provides a lightweight, efficient, and highly secure alternative that is well-suited to resource-constrained IoT devices.

## Understanding HMAC Signatures

An **HMAC** is a specific type of message authentication code that involves a cryptographic hash function and a secret key. In the case of Brine devices, the secret key is a pre-shared key (PSK) that is securely provisioned on each device during the initial setup process.

The HMAC algorithm works by combining the request data with the PSK and hashing the result using a cryptographic hash function (typically SHA-256). This produces a unique HMAC signature for the request, which can be verified by any party that also possesses the PSK.

In the Brine infrastructure, the process works as follows:
1.  **Device Side**:
    The Brine device generates an HMAC signature for each request it sends to the Firebase backend by:
     - Creating a hash of the request data.
	 - Combining the hash with the PSK.
	 - Applying the SHA-256 algorithm to produce the HMAC signature.
2.	**Backend Side**:
    When the Firebase backend receives a request, it performs the same HMAC generation process using the PSK associated with the device. If the generated HMAC matches the one provided in the request, the backend verifies that the request is authentic and unmodified.

## How HMAC Signatures Ensure Security

HMAC signatures provide two key security properties:

1.	**Authenticity**:
    Since only devices with the correct PSK can generate a valid HMAC signature, the backend can be confident that the request originates from an authorized device.
2.	**Integrity**:
    If any part of the request data is tampered with during transmission, the resulting HMAC signature will not match, allowing the backend to detect and reject such tampered requests.

This approach ensures that only legitimate devices can interact with the backend, preventing unauthorized data submission and potential security breaches.

## Example Sequence Diagram

The following sequence diagram illustrates the HMAC-based request signing and verification process:

```mermaid
sequenceDiagram
    participant D as Brine Device
    participant B as Firebase Backend
    D->>D: Retrieve PSK from secure storage
    D->>D: Generate HMAC signature for request
    D->>B: Send request data and HMAC signature
    B->>B: Retrieve PSK for the device
    B->>B: Recompute HMAC signature
    B->>B: Compare received and recomputed HMAC signatures
    alt Signatures match
        B->>D: Request accepted
    else Signatures do not match
        B->>D: Request rejected
    end
```

## Provisioning and PSK Management

The security of the HMAC-based system relies on the secure management of PSKs. The Brine infrastructure includes the following mechanisms for provisioning and managing PSKs:

1.	**Initial Provisioning**:
    During the initial setup, the mobile app securely transfers a unique PSK to the Brine device via a secure Bluetooth connection. The device stores the PSK in its non-volatile storage (NVS) for later use.
2.	**PSK Rotation**:
    If a device is compromised or if the PSK needs to be updated for any reason, the PSK can be rotated by re-provisioning the device with a new key.
3.	**PSK Revocation**:
    In the event that a device is lost or compromised, the associated PSK can be revoked in the backend, ensuring that requests from the compromised device are no longer accepted.

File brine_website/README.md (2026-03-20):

# Brine

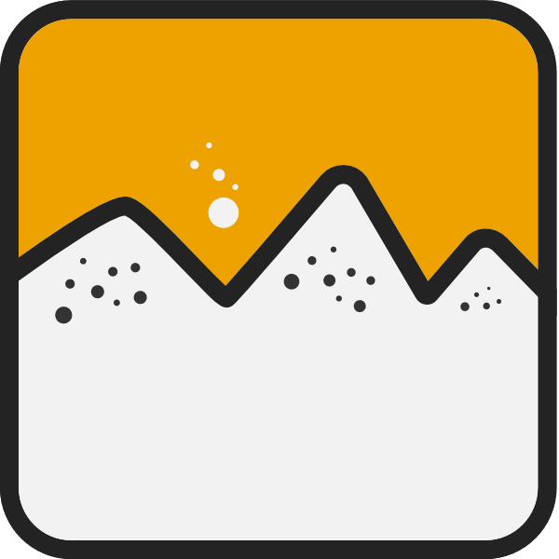
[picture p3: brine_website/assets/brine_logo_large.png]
Brine logo


A website for the Brine Monitor, an IoT device that monitors the amount of salt remaining
in a water softener.

# Hello :wave:

Do you ever forget to refill the salt in your water softener? Yes you do. It is probably a safe
bet to say that everybody who has a water softener in their home forgets to refill the salt from
time to time. That "time to time" might even be several months in row.

The Brine water softener monitor keeps track of the amount of salt remaining in your water softener
and delivers alerts when the level is low. With this tool, you can keep your water softener filled
with salt and working properly, which, in turn, will keep your appliances free of mineral deposits,
your hands and hair well-moisturized, your laundry machine effective, and spots off your dishes.

## Test locally with dhttpd

The **dhttpd** package can be used to serve a Flutter web app on a local machine for development 
and testing.

> TL;DR `dart pub global run dhttpd` inside build/web

Here are the steps you need to follow:

1. First, make sure you have Dart installed. If you have Flutter SDK installed, Dart comes along with it.
2. Now, you need to activate the "dhttpd" package by running the following command in your terminal: `dart pub global activate dhttpd`
3. Navigate to your build directory of your Flutter web application which should be "build/web" inside your project folder. You can use the command line to navigate to that directory: `cd <path to your project folder>/build/web`
4. Once you're inside your "build/web" directory, you can start the server using dhttpd: `dart pub global run dhttpd`
5. Now you can open your web browser and type in "localhost:8080". You should be able to see your Flutter web app running.

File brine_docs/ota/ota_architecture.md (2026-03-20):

# Brine OTA System Architecture

## System Overview

```
┌─────────────────────────────────────────────────────────────────┐
│                         Brine OTA System                         │
└─────────────────────────────────────────────────────────────────┘

┌──────────────────┐         ┌──────────────────┐         ┌──────────────────┐
│  Brine Device    │         │  Cloud Backend   │         │   Mobile App     │
│   (ESP32 C++)    │         │   (Firebase)     │         │  (Flutter/Dart)  │
└──────────────────┘         └──────────────────┘         └──────────────────┘
        │                             │                             │
        │                             │                             │
        ▼                             ▼                             ▼
┌──────────────────┐         ┌──────────────────┐         ┌──────────────────┐
│   OTAService     │         │ Cloud Functions  │         │  Future: BLE OTA │
│   WiFiService    │         │   Firestore      │         │   (Not Yet)      │
│   DeepSleep      │         │   Storage        │         │                  │
└──────────────────┘         └──────────────────┘         └──────────────────┘
```

## Component Diagram

```
┌─────────────────────────────────────────────────────────────────────────────┐
│                              Cloud Infrastructure                            │
├─────────────────────────────────────────────────────────────────────────────┤
│                                                                              │
│  ┌────────────────────────┐      ┌────────────────────────┐                │
│  │  Cloud Function        │      │  Firestore Database    │                │
│  │  checkFirmwareUpdate   │◄────►│  firmware_versions     │                │
│  │                        │      │  - version             │                │
│  │  - Check version       │      │  - version_number      │                │
│  │  - Return download URL │      │  - download_url        │                │
│  │  - Track checks        │      │  - active              │                │
│  └────────────────────────┘      │  - release_notes       │                │
│             │                     └────────────────────────┘                │
│             │                                                                │
│             │                     ┌────────────────────────┐                │
│             │                     │  Firebase Storage      │                │
│             └────────────────────►│  /firmware/            │                │
│                                   │  - brine-firmware-*.bin│                │
│                                   └────────────────────────┘                │
│                                                                              │
└─────────────────────────────────────────────────────────────────────────────┘
                                      │
                                      │ HTTPS
                                      │
                                      ▼
┌─────────────────────────────────────────────────────────────────────────────┐
│                              Brine Device (ESP32)                            │
├─────────────────────────────────────────────────────────────────────────────┤
│                                                                              │
│  ┌────────────────────────┐      ┌────────────────────────┐                │
│  │  main.cpp              │      │  OTAService            │                │
│  │                        │      │                        │                │
│  │  - Wake from sleep     │      │  - checkForUpdate()    │                │
│  │  - Connect WiFi        │─────►│  - performCloudUpdate()│                │
│  │  - Check for update    │      │  - Download firmware   │                │
│  │  - Take measurements   │      │  - Write to OTA        │                │
│  │  - Deep sleep          │      │  - Verify & reboot     │                │
│  └────────────────────────┘      └────────────────────────┘                │
│             │                                                                │
│             │                     ┌────────────────────────┐                │
│             │                     │  ESP32 Update Library  │                │
│             └────────────────────►│  - OTA partition       │                │
│                                   │  - Verification        │                │
│                                   │  - Boot management     │                │
│                                   └────────────────────────┘                │
│                                                                              │
└─────────────────────────────────────────────────────────────────────────────┘
```

## Update Flow Sequence

```
Device                  Cloud Function              Firestore               Storage
  │                           │                         │                      │
  │ Wake from sleep           │                         │                      │
  │ Connect WiFi              │                         │                      │
  │                           │                         │                      │
  │ POST /checkFirmwareUpdate │                         │                      │
  │ {device_id, version}      │                         │                      │
  ├──────────────────────────►│                         │                      │
  │                           │                         │                      │
  │                           │ Query latest firmware   │                      │
  │                           ├────────────────────────►│                      │
  │                           │                         │                      │
  │                           │◄────────────────────────┤                      │
  │                           │ {version, url, active}  │                      │
  │                           │                         │                      │
  │                           │ Compare versions        │                      │
  │                           │                         │                      │
  │◄──────────────────────────┤                         │                      │
  │ {update_available: true,  │                         │                      │
  │  download_url, version}   │                         │                      │
  │                           │                         │                      │
  │ GET download_url          │                         │                      │
  ├─────────────────────────────────────────────────────────────────────────►│
  │                           │                         │                      │
  │◄────────────────────────────────────────────────────────────────────────┤
  │ Firmware binary (streaming)                         │                      │
  │                           │                         │                      │
  │ Write to OTA partition    │                         │                      │
  │ Verify firmware           │                         │                      │
  │ Reboot                    │                         │                      │
  │                           │                         │                      │
  ▼                           │                         │                      │
Boot with new firmware        │                         │                      │
```

## State Machine

```
┌─────────────┐
│   STARTUP   │
└──────┬──────┘
       │
       ▼
┌─────────────┐
│ WAKE_REASON │
└──────┬──────┘
       │
       ├─── Timer ────────────────┐
       │                          │
       └─── Button ───────────┐   │
                              │   │
                              ▼   ▼
                         ┌────────────┐
                         │ WIFI_CONNECT│
                         └──────┬─────┘
                                │
                                ▼
                         ┌────────────┐
                         │ CHECK_OTA  │
                         └──────┬─────┘
                                │
                    ┌───────────┴───────────┐
                    │                       │
              Update Available        No Update
                    │                       │
                    ▼                       ▼
            ┌──────────────┐        ┌──────────────┐
            │ DOWNLOAD_FW  │        │ NORMAL_OPS   │
            └──────┬───────┘        └──────┬───────┘
                   │                       │
                   ▼                       │
            ┌──────────────┐              │
            │  VERIFY_FW   │              │
            └──────┬───────┘              │
                   │                       │
                   ▼                       │
            ┌──────────────┐              │
            │   REBOOT     │              │
            └──────────────┘              │
                                          │
                                          ▼
                                   ┌──────────────┐
                                   │ TAKE_READING │
                                   └──────┬───────┘
                                          │
                                          ▼
                                   ┌──────────────┐
                                   │ UPLOAD_DATA  │
                                   └──────┬───────┘
                                          │
                                          ▼
                                   ┌──────────────┐
                                   │ DEEP_SLEEP   │
                                   └──────────────┘
```

## Data Flow

### Update Check Request
```
Device → Cloud Function
{
  "device_id": "brine-device-123",
  "current_version": "1.0.0"
}
```

### Update Check Response (Update Available)
```
Cloud Function → Device
{
  "update_available": true,
  "latest_version": "1.1.0",
  "download_url": "https://storage.googleapis.com/...",
  "release_notes": "Bug fixes and improvements"
}
```

### Update Check Response (No Update)
```
Cloud Function → Device
{
  "update_available": false,
  "message": "Current version is up to date.",
  "current_version": "1.0.0",
  "latest_version": "1.0.0"
}
```

### Firestore Document Structure
```
firmware_versions/{doc_id}
{
  "version": "1.1.0",
  "version_number": 110,
  "download_url": "https://storage.googleapis.com/...",
  "release_notes": "Bug fixes and improvements",
  "active": true,
  "created_at": "2025-11-27T10:00:00Z",
  "file_size": 987654,
  "checksum": "sha256:..." (optional)
}
```

### Device Tracking
```
devices/{device_id}
{
  // ... existing fields ...
  "last_update_check": "2025-11-27T10:30:00Z",
  "available_firmware_version": "1.1.0",
  "current_firmware_version": "1.0.0" (future)
}
```

## Network Architecture

```
┌─────────────────────────────────────────────────────────────┐
│                      Internet                                │
└─────────────────────────────────────────────────────────────┘
                              │
                              │
        ┌─────────────────────┼─────────────────────┐
        │                     │                     │
        ▼                     ▼                     ▼
┌──────────────┐    ┌──────────────┐    ┌──────────────┐
│   Device     │    │   Firebase   │    │   Mobile     │
│   (WiFi)     │    │   (Cloud)    │    │   App        │
└──────────────┘    └──────────────┘    └──────────────┘
        │                     │                     │
        │                     │                     │
        │    HTTPS/443        │                     │
        ├────────────────────►│                     │
        │                     │                     │
        │◄────────────────────┤                     │
        │                     │                     │
        │                     │    HTTPS/443        │
        │                     │◄────────────────────┤
        │                     │                     │
        │                     ├────────────────────►│
        │                     │                     │
```

## Security Architecture

```
┌─────────────────────────────────────────────────────────────┐
│                      Security Layers                         │
├─────────────────────────────────────────────────────────────┤
│                                                              │
│  Layer 1: Transport Security                                │
│  ┌────────────────────────────────────────────────────┐    │
│  │  HTTPS/TLS for all cloud communications            │    │
│  │  - Encrypted data in transit                       │    │
│  │  - Certificate validation                          │    │
│  └────────────────────────────────────────────────────┘    │
│                                                              │
│  Layer 2: Access Control                                    │
│  ┌────────────────────────────────────────────────────┐    │
│  │  Firebase Storage Rules                            │    │
│  │  - Public read for /firmware/*                     │    │
│  │  - Authenticated write only                        │    │
│  └────────────────────────────────────────────────────┘    │
│                                                              │
│  Layer 3: Version Control                                   │
│  ┌────────────────────────────────────────────────────┐    │
│  │  Semantic versioning prevents downgrades           │    │
│  │  Active flag allows disabling versions             │    │
│  └────────────────────────────────────────────────────┘    │
│                                                              │
│  Layer 4: Verification (Future)                             │
│  ┌────────────────────────────────────────────────────┐    │
│  │  Firmware signature verification                   │    │
│  │  Checksum validation                               │    │
│  │  Device authentication                             │    │
│  └────────────────────────────────────────────────────┘    │
│                                                              │
└─────────────────────────────────────────────────────────────┘
```

## Deployment Architecture

```
┌─────────────────────────────────────────────────────────────┐
│                    Development Environment                   │
├─────────────────────────────────────────────────────────────┤
│                                                              │
│  ┌──────────────┐      ┌──────────────┐                    │
│  │  Local Dev   │      │  Firebase    │                    │
│  │  Machine     │─────►│  Emulator    │                    │
│  │              │      │  Suite       │                    │
│  └──────────────┘      └──────────────┘                    │
│                                                              │
│  FLAVOR=1 (Dev)                                             │
│  Endpoint: http://192.168.86.39:5001/...                   │
│                                                              │
└─────────────────────────────────────────────────────────────┘
                              │
                              │ Deploy
                              ▼
┌─────────────────────────────────────────────────────────────┐
│                    Production Environment                    │
├─────────────────────────────────────────────────────────────┤
│                                                              │
│  ┌──────────────┐      ┌──────────────┐                    │
│  │  Firebase    │      │  Cloud       │                    │
│  │  Hosting     │      │  Functions   │                    │
│  │              │      │              │                    │
│  └──────────────┘      └──────────────┘                    │
│                                                              │
│  ┌──────────────┐      ┌──────────────┐                    │
│  │  Firestore   │      │  Storage     │                    │
│  │  Database    │      │  Buckets     │                    │
│  │              │      │              │                    │
│  └──────────────┘      └──────────────┘                    │
│                                                              │
│  FLAVOR=2 (Prod)                                            │
│  Endpoint: https://checkfirmwareupdate-7wo3szegoq-uc...    │
│                                                              │
└─────────────────────────────────────────────────────────────┘
```

## Future: Bluetooth OTA Architecture

```
┌─────────────────────────────────────────────────────────────┐
│                    Bluetooth OTA (Future)                    │
├─────────────────────────────────────────────────────────────┤
│                                                              │
│  Mobile App                          Brine Device           │
│  ┌──────────────┐                   ┌──────────────┐       │
│  │              │                   │              │       │
│  │  Download    │                   │  BLE Server  │       │
│  │  Firmware    │                   │              │       │
│  │  from Cloud  │                   │  OTA Service │       │
│  │              │                   │  UUID: 0x...  │       │
│  └──────┬───────┘                   └──────▲───────┘       │
│         │                                  │               │
│         │         BLE Connection           │               │
│         └──────────────────────────────────┘               │
│                                                              │
│  Characteristics:                                           │
│  - Control (Write): START, ABORT, FINALIZE                 │
│  - Data (Write): Firmware chunks (512 bytes)               │
│  - Status (Read/Notify): Progress updates                  │
│                                                              │
└─────────────────────────────────────────────────────────────┘
```

## Monitoring Architecture

```
┌─────────────────────────────────────────────────────────────┐
│                      Monitoring & Analytics                  │
├─────────────────────────────────────────────────────────────┤
│                                                              │
│  ┌──────────────────────────────────────────────────┐      │
│  │  Cloud Function Logs                             │      │
│  │  - Update check requests                         │      │
│  │  - Version comparisons                           │      │
│  │  - Errors and exceptions                         │      │
│  └──────────────────────────────────────────────────┘      │
│                                                              │
│  ┌──────────────────────────────────────────────────┐      │
│  │  Firestore Tracking                              │      │
│  │  - last_update_check per device                  │      │
│  │  - available_firmware_version                    │      │
│  │  - Update success/failure rates                  │      │
│  └──────────────────────────────────────────────────┘      │
│                                                              │
│  ┌──────────────────────────────────────────────────┐      │
│  │  Device Serial Logs                              │      │
│  │  - Update progress                               │      │
│  │  - Download status                               │      │
│  │  - Verification results                          │      │
│  └──────────────────────────────────────────────────┘      │
│                                                              │
│  ┌──────────────────────────────────────────────────┐      │
│  │  Future: Analytics Dashboard                     │      │
│  │  - Fleet-wide update status                      │      │
│  │  - Version distribution                          │      │
│  │  - Update success metrics                        │      │
│  └──────────────────────────────────────────────────┘      │
│                                                              │
└─────────────────────────────────────────────────────────────┘
```

## File Structure

```
Brine/
├── brine_firmware/
│   ├── include/
│   │   └── OTAService.h              # OTA service interface
│   ├── lib/
│   │   └── OTAService/
│   │       └── OTAService.cpp        # OTA implementation
│   ├── src/
│   │   └── main.cpp                  # Main firmware (OTA integrated)
│   ├── OTA_IMPLEMENTATION.md         # Firmware OTA docs
│   ├── BLUETOOTH_OTA_DESIGN.md       # BLE OTA design
│   └── deploy_firmware.sh            # Deployment script
│
├── brine_cloud_functions/
│   ├── functions/
│   │   ├── src/
│   │   │   └── checkFirmwareUpdate.cjs  # Update check function
│   │   ├── test/
│   │   │   └── checkFirmwareUpdate.test.cjs  # Tests
│   │   └── index.cjs                 # Function exports
│   ├── manage_firmware.js            # Firestore management
│   └── OTA_SETUP.md                  # Cloud setup docs
│
├── OTA_QUICK_START.md                # Quick reference
├── OTA_IMPLEMENTATION_SUMMARY.md     # Implementation summary
├── OTA_DEPLOYMENT_CHECKLIST.md       # Deployment checklist
└── OTA_ARCHITECTURE.md               # This file
```

## Technology Stack

### Device (ESP32)
- **Language**: C++
- **Framework**: Arduino
- **Platform**: ESP32 (Seeed XIAO ESP32-S3)
- **Libraries**: 
  - ESP32 Update (OTA)
  - HTTPClient (Downloads)
  - ArduinoJson (Parsing)
  - WiFi (Connectivity)

### Cloud (Firebase)
- **Functions**: Node.js (CommonJS)
- **Database**: Firestore
- **Storage**: Firebase Storage
- **Hosting**: Cloud Run (auto-scaled)

### Tools
- **Build**: PlatformIO
- **Deploy**: Firebase CLI
- **Testing**: Jest
- **Management**: Node.js scripts

## Performance Characteristics

### Update Check
- **Frequency**: Once per wake cycle (24 hours)
- **Duration**: ~2-5 seconds
- **Data Transfer**: ~500 bytes (request + response)
- **Battery Impact**: Minimal

### Firmware Download
- **Size**: ~500KB - 1.5MB
- **Duration**: ~30-60 seconds (depends on WiFi)
- **Data Transfer**: Firmware size
- **Battery Impact**: Moderate (5-10% battery)

### Update Installation
- **Duration**: ~10-20 seconds
- **Verification**: ~5 seconds
- **Reboot**: ~5 seconds
- **Total**: ~1-2 minutes end-to-end

## Scalability

### Current Capacity
- **Devices**: Unlimited (Firebase scales automatically)
- **Concurrent Updates**: Limited by WiFi bandwidth
- **Storage**: Unlimited (pay per GB)
- **Function Invocations**: 2M free/month, then pay per use

### Optimization Strategies
- Stagger update checks (random delay)
- Cache firmware in CDN
- Compress firmware binaries
- Delta updates (future)
- Scheduled update windows (future)

## Reliability

### Failure Modes
1. **Network Failure**: Retry on next wake cycle
2. **Download Failure**: Abort, retry later
3. **Verification Failure**: Abort, stay on current version
4. **Installation Failure**: ESP32 boots to previous version
5. **Cloud Function Error**: Device continues normal operation

### Recovery Mechanisms
- Automatic retry on next wake
- Rollback via active flag
- ESP32 bootloader fallback
- Device continues operation on failure
- No bricking risk

## Cost Analysis

### Per Device Per Month
- **Function Invocations**: ~30 (1 per day)
- **Firestore Reads**: ~30
- **Firestore Writes**: ~30
- **Storage**: ~1MB (shared across fleet)
- **Bandwidth**: ~1MB (if update available)

### Fleet of 1000 Devices
- **Function Invocations**: ~30,000/month (free tier: 2M)
- **Firestore Operations**: ~60,000/month (free tier: 50K reads, 20K writes)
- **Storage**: ~5MB (last 5 versions)
- **Bandwidth**: Variable (depends on update frequency)

**Estimated Cost**: $0-5/month for 1000 devices (mostly free tier)

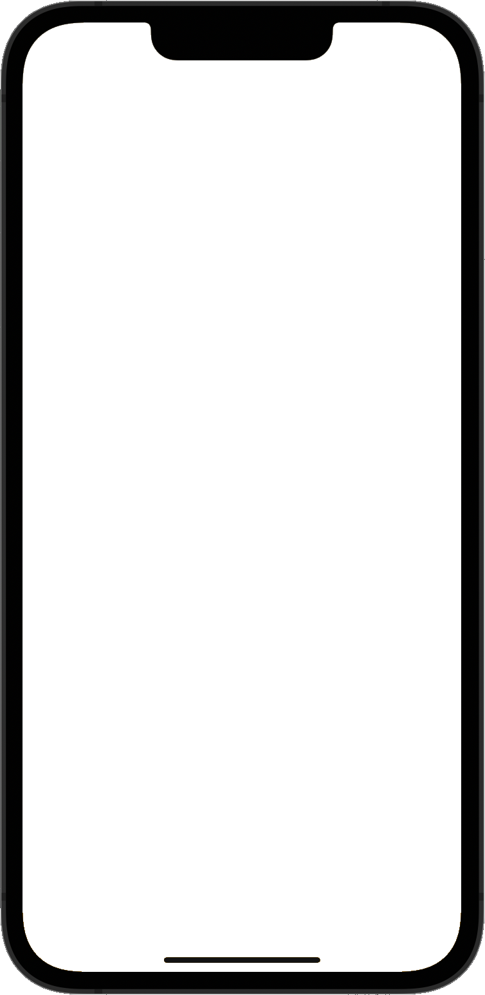
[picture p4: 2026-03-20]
brine_website/assets/iphone13_mockup.png

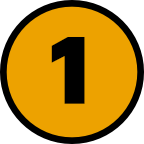
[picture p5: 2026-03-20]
brine_website/assets/numeral_1.png

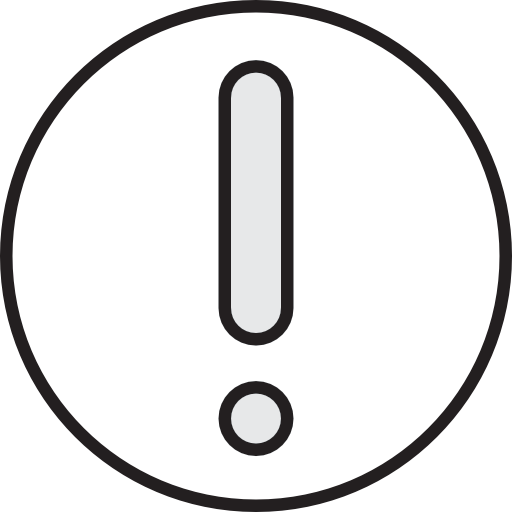
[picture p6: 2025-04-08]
brine_app/assets/error.png

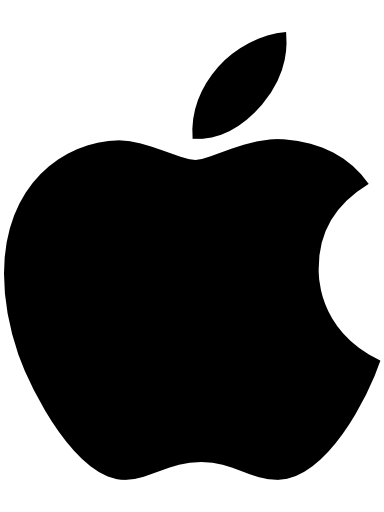
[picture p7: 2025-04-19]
brine_app/assets/apple.png

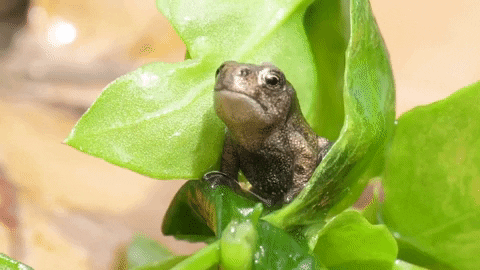
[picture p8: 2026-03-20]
brine_website/assets/frog_thanks.gif

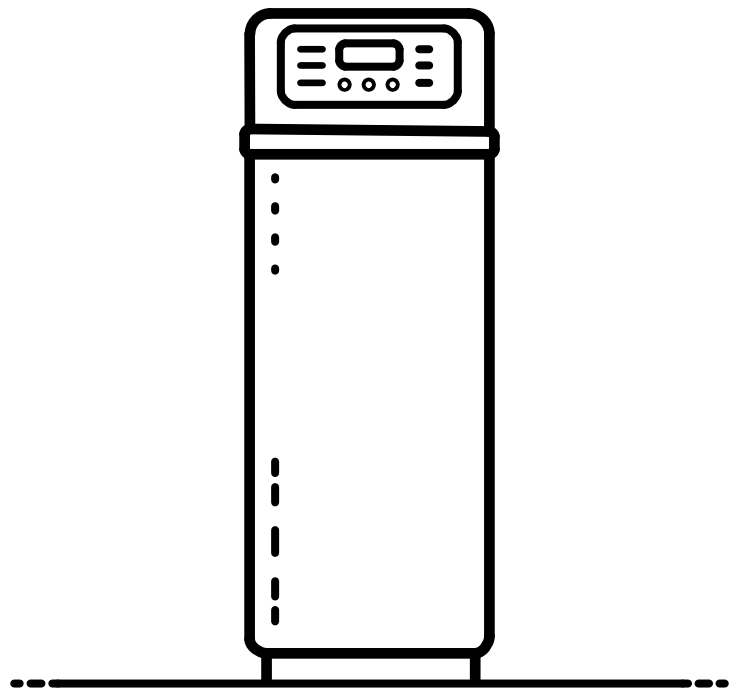
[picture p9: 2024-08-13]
brine_app/assets/water_softener_outline.png

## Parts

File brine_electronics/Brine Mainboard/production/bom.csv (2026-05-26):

Designator | Footprint | Quantity | Value | LCSC Part #
C1, C5 | 0805 | 2 | 100uF
C2 | 0805 | 1 | 4.7uF
C3 | 0805 | 1 | 0.1uF
C4 | CP_EIA-2012-12_Kemet-R | 1 | 1uF
D1 | SOT-323_SC-70 | 1 | BAT54W
D2 | LED_SK6812_PLCC4_5.0x5.0mm_P3.2mm | 1 | SK6812
J1 | JST_PH_S2B-PH-K_1x02_P2.00mm_Horizontal | 1 | BATT
J2 | SolderWirePad_1x01_SMD_1.5x3mm | 1 | BATT_CRG_GND
J3 | SolderWirePad_1x01_SMD_1.5x3mm | 1 | BATT_CRG_BATT
J4 | PinHeader_1x01_P1.00mm_Vertical | 1 | BATT_CRG_BATT
J5 | PinHeader_1x01_P1.00mm_Vertical | 1 | BATT_CRG_GND
Q1 | SOT-23 | 1 | AO3407A
R1 | 0805 | 1 | 220k
R2, R6, R7 | 0805 | 3 | 100k
R3, R5, R8 | 0805 | 3 | 10k
R4 | 0805 | 1 | 330
S2 | TS1187ABAB | 1 | TS-1187A-B-A-B
SCL1, SDA1 | 0805 | 2 | 2.2k
U1 | XIAO-ESP32S3-DIP | 1 | XIAO-ESP32-S3-SMD
U2 | VL53L1CXV0FY1 | 1 | VL53L1CXV0FY1
U3 | TSOT-23_TS8 | 1 | LTC2954
U4 | SOT-23-5 | 1 | 74AHCT1G125

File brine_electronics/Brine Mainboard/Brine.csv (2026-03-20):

Reference | Qty | Value | DNP | Exclude from BOM | Exclude from Board | Footprint | Datasheet | Mouser Link
C1,C4,C6,C7,C8,C12 | 6 | 0.1uF |  |  |  | Capacitor_SMD:C_0805_2012Metric |  | https://www.mouser.com/ProductDetail/Wurth-Elektronik/885012207098
C2,C3 | 2 | 4.7uF |  |  |  | Capacitor_SMD:C_0805_2012Metric |  | https://www.mouser.com/ProductDetail/Wurth-Elektronik/885012207025?qs=0KOYDY2FL295qqOcOj%252BGAw%3D%3D
C5,C9 | 2 | 10uF |  |  |  | Capacitor_SMD:C_0805_2012Metric |  | https://www.mouser.com/ProductDetail/Vishay-Sprague/TMCP0J106KTR2F
D2 | 1 | YELLOW |  |  |  | LED_SMD:LED_0805_2012Metric |  | https://www.mouser.com/ProductDetail/ams-OSRAM/LY-R976-PS-36?qs=K5ta8V%252BWhtb8kF0FHqpCJQ%3D%3D
D3,D6 | 2 | RED |  |  |  | LED_SMD:LED_0805_2012Metric |  | https://www.mouser.com/ProductDetail/ams-OSRAM/LS-R976-NR-1
D4 | 1 | GREEN |  |  |  | LED_SMD:LED_0805_2012Metric |  | https://www.mouser.com/ProductDetail/ams-OSRAM/LG-R971-KN-1?qs=LsPilcdHE7EX1EB7GCLHxg%3D%3D
D5 | 1 | ORANGE |  |  |  | LED_SMD:LED_0805_2012Metric |  | https://www.mouser.com/ProductDetail/ams-OSRAM/LO-R976-PS-1?qs=K5ta8V%252BWhtZwfsJidIA9Vg%3D%3D
H1,H2 | 2 | MountingHole |  | Excluded from BOM |  | MountingHole:MountingHole_3.2mm_M3 | ~
J2 | 1 | VL53L1X |  |  |  | Connector_PinHeader_2.54mm:PinHeader_1x06_P2.54mm_Vertical | ~
J13,J14 | 2 | Fuel Gauge |  |  |  | Connector_PinSocket_2.54mm:PinSocket_1x03_P2.54mm_Vertical | ~
J15 | 1 | AVR-ISP-6 |  |  |  | Connector_IDC:IDC-Header_2x03_P2.54mm_Vertical | ~
J20 | 1 | LED_ENABLE |  |  |  | Connector_PinHeader_2.54mm:PinHeader_1x02_P2.54mm_Vertical | ~
Q1,Q9,Q10,Q11,Q12,Q13 | 6 | MMBT3904 |  |  |  | PCM_Package_TO_SOT_SMD_AKL:SOT-23 | https://www.tme.eu/Document/12bff749841e3a356e683e9a8e7e4119/2N3904BU-DTE.pdf
Q2,Q3 | 2 | IRLML6402 |  |  |  | PCM_Package_TO_SOT_SMD_AKL:SOT-23 | https://www.tme.eu/Document/24d01ab3c34ac9a6011dc0151b11bc25/IRLML6402TRPBF.pdf
R1,R2,R3,R18,R20 | 5 | 10k |  |  |  | Resistor_SMD:R_0805_2012Metric |  | https://www.mouser.com/ProductDetail/603-AC0805FR-0710KL,https://www.mouser.com/ProductDetail/YAGEO/AC0805FR-0710KL
R5 | 1 | 2k |  |  |  | Resistor_SMD:R_0805_2012Metric |  | https://www.mouser.com/ProductDetail/YAGEO/SR2512FK-7W2KL?qs=rrS6PyfT74czPCqB8W0vDw%3D%3D
R6,R16,R17,R19 | 4 | 1k |  |  |  | Resistor_SMD:R_0805_2012Metric |  | https://www.mouser.com/ProductDetail/YAGEO/RC0603DR-071KL?qs=v19ZECn5zGGaFLRsX1URiQ%3D%3D
R7,R8,R9 | 3 | 2.2k |  |  |  | Resistor_SMD:R_0805_2012Metric |  | https://www.mouser.com/ProductDetail/YAGEO/RC0805JR-072K2L?qs=KyGMWp10Ukt1e57HDpPYkQ%3D%3D
R10,R11 | 2 | 100k |  |  |  | Resistor_SMD:R_0805_2012Metric |  | https://www.mouser.com/ProductDetail/YAGEO/RC0805FR-7W100KL?qs=tggtontpCXPWF1UQCat0Yw%3D%3D
R12,R13 | 2 | 1M |  |  |  | Resistor_SMD:R_0805_2012Metric |  | https://www.mouser.com/ProductDetail/YAGEO/AC0805DR-071ML?qs=r5DSvlrkXmJEKNZJOwnykA%3D%3D
R14,R15 | 2 | 5.1k |  |  |  | Resistor_SMD:R_0805_2012Metric |  | https://www.mouser.com/ProductDetail/YAGEO/SR1206JR-7W5K1L?qs=TyBUSTk9pD%2F2IxX2DTBDNA%3D%3D
S1 | 1 | EN |  |  |  | TL3342F260QG:TL3342F260QG | https://configured-product-images.s3.amazonaws.com/2D/specs/TL3342F260QG.pdf | https://www.mouser.com/ProductDetail/E-Switch/TL3342F260QG?qs=6C6BR4UgC3Of90YOH%2FEXyw%3D%3D
S2 | 1 | BOOT |  |  |  | TL3342F260QG:TL3342F260QG | https://configured-product-images.s3.amazonaws.com/2D/specs/TL3342F260QG.pdf | https://www.mouser.com/ProductDetail/E-Switch/TL3342F260QG?qs=6C6BR4UgC3Of90YOH%2FEXyw%3D%3D
SW1 | 1 | SW_SPST_LED |  |  |  | Button_Switch_THT:BUTTON_LED | ~
U1 | 1 | ESP32-S3-MINI-1 |  |  |  | RF_Module:ESP32-S2-MINI-1 | https://www.espressif.com/sites/default/files/documentation/esp32-s3-mini-1_mini-1u_datasheet_en.pdf
U2 | 1 | MCP73831-4-OT |  |  |  | Package_TO_SOT_SMD:SOT-23-5 | http://ww1.microchip.com/downloads/en/DeviceDoc/20001984g.pdf | https://www.mouser.com/ProductDetail/Microchip-Technology/MCP73831T-2ACI-OT?qs=yUQqVecv4qvbBQBGbHx0Mw%3D%3D
U4 | 1 | TLV1117-33 |  |  |  | PCM_Package_TO_SOT_SMD_AKL:TO-252-3_TabPin2_ThermalVias | http://www.ti.com/lit/ds/symlink/tlv1117.pdf
U5 | 1 | ATtiny841-SS |  |  |  | Package_SO:SOIC-14_3.9x8.7mm_P1.27mm | http://ww1.microchip.com/downloads/en/DeviceDoc/Atmel-8495-8-bit-AVR-Microcontrollers-ATtiny441-ATtiny841_Datasheet.pdf | https://www.mouser.com/ProductDetail/Microchip-Technology/ATTINY841-SSU?qs=HVbQlW5zcXVaBIh573n%252Bhw%3D%3D
USB-C1 | 1 | Conn_01x06_Pin |  |  |  | Connector_PinHeader_2.54mm:PinHeader_1x06_P2.54mm_Vertical | ~

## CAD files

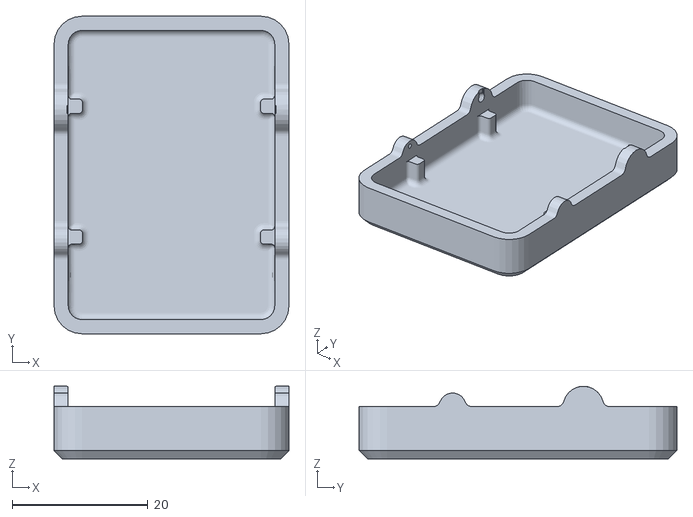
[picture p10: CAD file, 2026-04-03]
brine_cad/STLs/brine_enclosure_bottom.stl
34.7 x 46.9 x 10.7

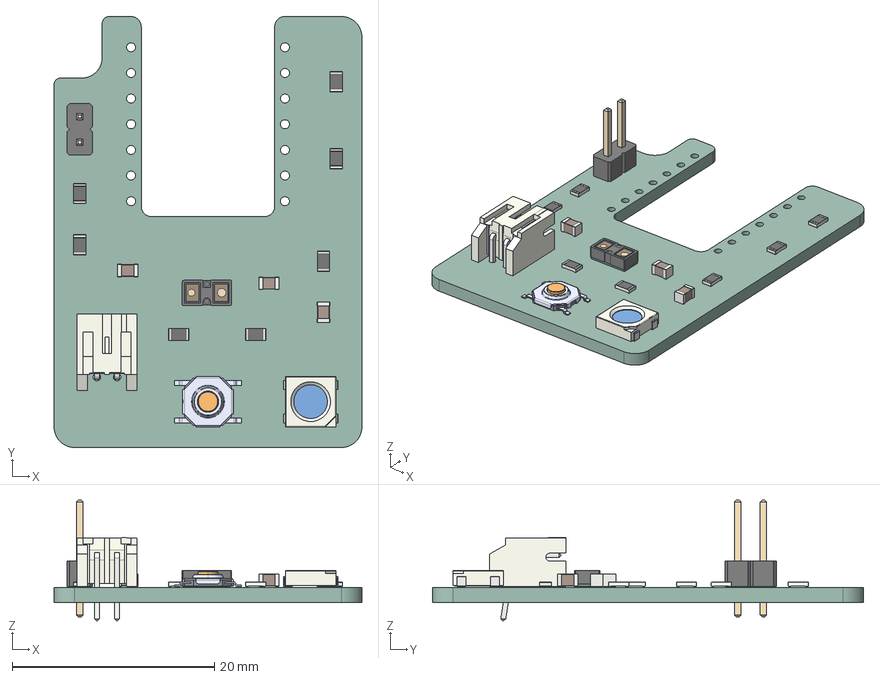
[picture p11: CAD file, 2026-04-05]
brine_electronics/Brine Mainboard/Brine.step
30.5 x 42.7 x 11.9 mm
R_0805_2012Metric x 7
PinHeader_1x02_P2.54mm_Vertical
C_0805_2012Metric x 3
LED_WS2812B_PLCC4_5.0x5.0mm_P3.2mm
ST_VL53L1x
JST_PH_S2B-PH-K_1x02_P2.00mm_Horizontal
TL3342F160QG
Brine_PCB

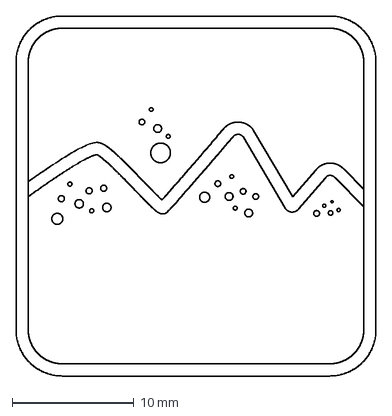
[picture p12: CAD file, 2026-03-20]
brine_logos/Brine_logo.dxf
29.5 x 29.5 mm

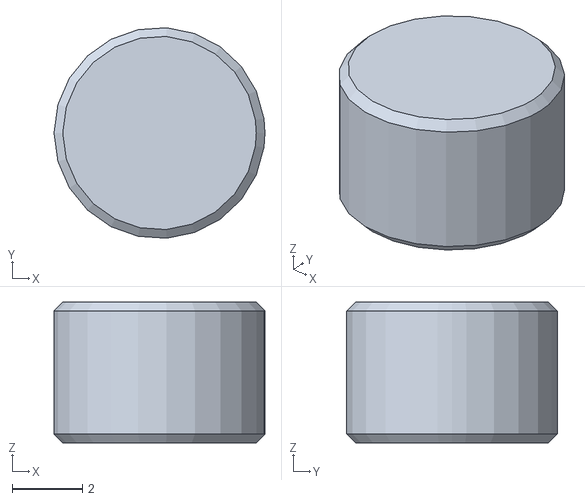
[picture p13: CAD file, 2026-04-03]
brine_cad/STLs/brine_enclosure_button.stl
6.00 x 5.99 x 4.00

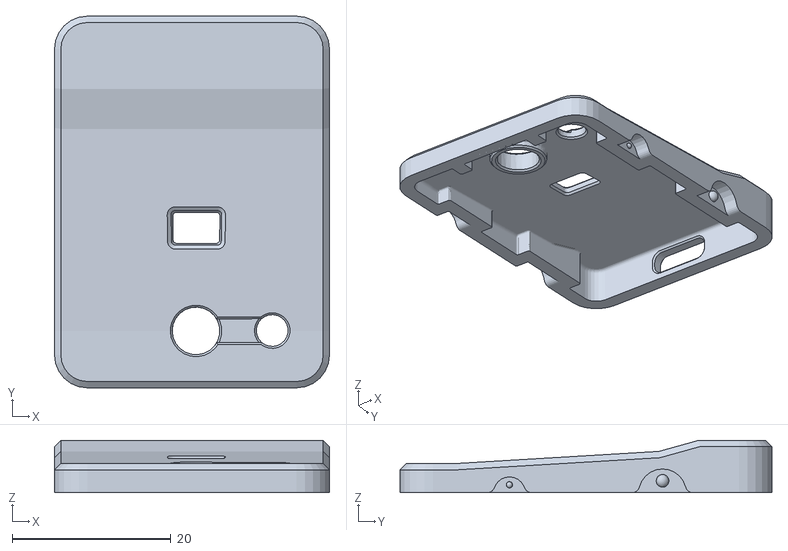
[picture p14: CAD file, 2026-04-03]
brine_cad/STLs/brine_enclosure_top.stl
34.7 x 46.9 x 6.62

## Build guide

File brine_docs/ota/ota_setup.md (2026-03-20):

# OTA Cloud Functions Setup Guide

## Overview

This guide explains how to set up and manage the cloud infrastructure for Brine's OTA firmware update system.

## Prerequisites

- Firebase project configured
- Firebase CLI installed and authenticated
- Node.js and npm installed
- Firestore database enabled
- Firebase Storage enabled

## Cloud Function: checkFirmwareUpdate

### Endpoint Details

**Development (Emulator)**:
```
http://localhost:5001/brine-3b212/us-central1/checkFirmwareUpdate
```

**Production**:
```
https://checkfirmwareupdate-7wo3szegoq-uc.a.run.app
```

### Request Format

```bash
curl -X POST https://checkfirmwareupdate-7wo3szegoq-uc.a.run.app \
  -H "Content-Type: application/json" \
  -d '{
    "device_id": "device-123",
    "current_version": "1.0.0"
  }'
```

### Response Format

**Update Available**:
```json
{
  "update_available": true,
  "latest_version": "1.1.0",
  "download_url": "https://firebasestorage.googleapis.com/...",
  "release_notes": "Bug fixes and improvements"
}
```

**No Update**:
```json
{
  "update_available": false,
  "message": "Current version is up to date.",
  "current_version": "1.0.0",
  "latest_version": "1.0.0"
}
```

## Firestore Setup

### Collection: firmware_versions

Create this collection in your Firestore database.

#### Document Structure

```javascript
{
  version: "1.1.0",              // String: Semantic version
  version_number: 110,           // Number: For sorting (major*100 + minor*10 + patch)
  download_url: "https://...",   // String: Firebase Storage URL
  release_notes: "...",          // String: Release notes (optional)
  active: true,                  // Boolean: Whether to offer this version
  created_at: "2025-11-27T...",  // String: ISO timestamp
  file_size: 1234567,            // Number: Size in bytes
  checksum: "sha256:..."         // String: Checksum (optional, for future use)
}
```

#### Indexes

Create a composite index for efficient queries:

**Collection**: `firmware_versions`
**Fields**:
- `version_number` (Descending)
- `active` (Ascending)

You can create this index by:
1. Running a query that requires it (Firebase will prompt you)
2. Or manually in Firebase Console: Firestore → Indexes → Create Index

### Collection: devices

The OTA system updates device documents with tracking information:

```javascript
{
  // ... existing device fields ...
  last_update_check: "2025-11-27T10:30:00Z",     // Last time device checked for updates
  available_firmware_version: "1.1.0",           // Latest version available to device
  current_firmware_version: "1.0.0"              // Currently running version (future)
}
```

## Deployment

### Deploy Cloud Functions

```bash
cd brine_cloud_functions
firebase deploy --only functions:checkFirmwareUpdate
```

### Deploy All Functions

```bash
firebase deploy --only functions
```

### Test Deployment

```bash
# Test the deployed function
curl -X POST https://checkfirmwareupdate-7wo3szegoq-uc.a.run.app \
  -H "Content-Type: application/json" \
  -d '{
    "device_id": "test-device",
    "current_version": "1.0.0"
  }'
```

## Firebase Storage Setup

### Storage Structure

```
firmware/
├── brine-firmware-1.0.0.bin
├── brine-firmware-1.1.0.bin
└── brine-firmware-1.2.0.bin
```

### Upload Firmware

```bash
# Upload firmware binary
firebase storage:upload path/to/firmware.bin --path firmware/brine-firmware-1.1.0.bin

# Get download URL
firebase storage:get-url firmware/brine-firmware-1.1.0.bin
```

### Storage Rules

Update `storage.rules` to allow device access:

```javascript
rules_version = '2';
service firebase.storage {
  match /b/{bucket}/o {
    // Allow public read access to firmware files
    match /firmware/{fileName} {
      allow read: if true;
    }
    
    // Restrict write access to authenticated users only
    match /firmware/{fileName} {
      allow write: if request.auth != null;
    }
  }
}
```

Deploy rules:
```bash
firebase deploy --only storage
```

## Managing Firmware Versions

### Adding a New Version

1. **Build firmware**:
```bash
cd brine_firmware
pio run -e seeed_xiao_esp32s3
```

2. **Upload to Storage**:
```bash
firebase storage:upload .pio/build/seeed_xiao_esp32s3/firmware.bin \
  --path firmware/brine-firmware-1.1.0.bin
```

3. **Get download URL**:
```bash
firebase storage:get-url firmware/brine-firmware-1.1.0.bin
```

4. **Add Firestore document**:

Using Firebase Console:
- Go to Firestore Database
- Navigate to `firmware_versions` collection
- Add document with the structure shown above

Using Firebase Admin SDK (Node.js):
```javascript
const admin = require('firebase-admin');
admin.initializeApp();

await admin.firestore().collection('firmware_versions').add({
  version: "1.1.0",
  version_number: 110,
  download_url: "https://firebasestorage.googleapis.com/...",
  release_notes: "Bug fixes and improvements",
  active: true,
  created_at: new Date().toISOString(),
  file_size: 987654
});
```

### Deactivating a Version

To prevent devices from updating to a specific version:

```javascript
await admin.firestore()
  .collection('firmware_versions')
  .doc('version-doc-id')
  .update({ active: false });
```

### Rollback Strategy

If a firmware version has issues:

1. Set problematic version to `active: false`
2. Ensure previous stable version has `active: true`
3. Devices will receive the stable version on next check

## Monitoring

### Cloud Function Logs

View logs in Firebase Console:
```
Firebase Console → Functions → checkFirmwareUpdate → Logs
```

Or using CLI:
```bash
firebase functions:log --only checkFirmwareUpdate
```

### Device Update Tracking

Query devices that checked for updates recently:

```javascript
const recentChecks = await admin.firestore()
  .collection('devices')
  .where('last_update_check', '>', new Date(Date.now() - 24*60*60*1000))
  .get();
```

Query devices with available updates:

```javascript
const devicesWithUpdates = await admin.firestore()
  .collection('devices')
  .where('available_firmware_version', '>', '1.0.0')
  .get();
```

## Testing

### Run Unit Tests

```bash
cd brine_cloud_functions/functions
npm test -- checkFirmwareUpdate.test.cjs
```

### Test with Emulator

1. **Start emulator**:
```bash
cd brine_cloud_functions
firebase emulators:start
```

2. **Add test data to Firestore emulator**:
```javascript
// Use Firebase Console UI at http://localhost:4000
// Or use Admin SDK pointing to emulator
```

3. **Test endpoint**:
```bash
curl -X POST http://localhost:5001/brine-3b212/us-central1/checkFirmwareUpdate \
  -H "Content-Type: application/json" \
  -d '{
    "device_id": "test-device",
    "current_version": "1.0.0"
  }'
```

## Security Considerations

### Current Implementation

- No authentication required (devices call directly)
- Public read access to firmware files in Storage
- Version comparison prevents downgrade attacks

### Recommended Enhancements

1. **Device Authentication**:
```javascript
// Add HMAC signature verification similar to updateDeviceLevels
const deviceId = req.headers['x-device-id'];
const providedHmac = req.headers['x-hmac-signature'];
// Verify HMAC...
```

2. **Rate Limiting**:
```javascript
// Implement rate limiting per device
// Prevent abuse of update checks
```

3. **Firmware Signing**:
```javascript
// Add digital signature to firmware_versions documents
// Verify signature on device before applying update
```

## Troubleshooting

### Function Returns No Firmware Versions

**Problem**: `firmware_versions` collection is empty

**Solution**: Add at least one firmware version document to Firestore

### Device Can't Download Firmware

**Problem**: Storage rules block access

**Solution**: Verify storage rules allow public read for `/firmware/*`

### Version Comparison Issues

**Problem**: Incorrect version format

**Solution**: Ensure versions follow semantic versioning (major.minor.patch)

### Function Timeout

**Problem**: Function takes too long to respond

**Solution**: 
- Check Firestore indexes are created
- Verify network connectivity
- Review function logs for errors

## Cost Optimization

### Storage Costs

- Firmware binaries are typically 500KB - 2MB
- Keep only recent versions (e.g., last 5 versions)
- Delete old firmware files from Storage

### Function Invocations

- Devices check for updates once per wake cycle (typically 24 hours)
- 1000 devices = ~30,000 invocations/month
- Well within Firebase free tier

### Firestore Reads

- Each update check = 1 read from `firmware_versions`
- Each update check = 1 write to `devices` (tracking)
- Optimize by caching latest version in memory (future enhancement)

## Future Enhancements

- [ ] Add device authentication to update endpoint
- [ ] Implement firmware signature verification
- [ ] Add support for device groups/channels (beta, stable, etc.)
- [ ] Create admin dashboard for firmware management
- [ ] Add automatic cleanup of old firmware files
- [ ] Implement update analytics and reporting
- [ ] Add support for forced updates
- [ ] Create webhook notifications for update events
- [ ] Add support for delta updates
- [ ] Implement A/B testing for firmware versions

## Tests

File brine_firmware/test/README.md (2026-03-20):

# README for Hardware-in-the-Loop (HITL) Tests

This directory contains Hardware-in-the-Loop (HITL) tests for each hardware component of the Brine IoT device. These 
tests are designed to interactively verify the functionality of the hardware components, sometimes by collecting 
feedback from a human tester over serial communication.

## Writing HITL Tests

Each hardware component should have a corresponding test file in this directory. The test file should be named 
`test_<component>.cpp`, where `<component>` is the name of the hardware component being tested, which in turn, is 
tyically represented by a class within the codebase that provides an interface for that hardware and allows for the 
encapsulation of these interfaces.

Each test file should include the following:

1. Include necessary libraries and headers.
2. Initialize the hardware component.
3. Write a setup function to initialize any necessary variables and resources such as an I2C bus.
4. Write a test function to perform the actual testing. This function should control the hardware component and,
optionally, ask the human tester to verify the result, when necessary.

Here is a pseudocode example of what a test file might look like:

```cpp
// Include necessary libraries and headers
#include <Arduino.h>
#include <Component.h>

// Initialize the Component object
Component component;

// Setup function
void setup() {
    // Initialize the hardware and variables
}

// Test function
void test_component() {
    // Perform an action on the component.
    TEST_ASSERT_TRUE(component.action());
}

// Register the test function
void loop() {
    test_component();
}
```

## Running HITL Tests

To run the HITL tests, you can use the PlatformIO CLI or the PlatformIO IDE.

### PlatformIO CLI

To run all tests in the `test` directory, use the following command in your terminal:

```
pio test
```

To run a specific test, use the `-e` option followed by the name of the environment and the `--filter` option followed 
by the name of the test. For example:

```
pio test -e uno --filter test_component
```

### PlatformIO IDE

To run tests in the PlatformIO IDE, click on the "PlatformIO" icon in the Activity Bar on the side of the window, then 
navigate to "Test" and click on the "Run" button.

## Interactive Testing

During the test, the tester may be asked to verify the result of each test step. The tester should observe the output
in the PlatformIO CLI and perform the requested actions as required by the test.

## Full System Test

The full system test, located in the *test_fullSystem* directory, is designed to run a comprehensive set of tests covering all hardware components and their interactions. Unlike individual component tests, which focus on testing specific hardware in isolation, the full system test ensures that all components work together correctly when integrated into the Brine IoT device.

### Running the Full System Test

To run the full system test, you can use the PlatformIO CLI:

```sh
pio test --filter test_fullSystem
```

Alternatively, if you are using the PlatformIO IDE, navigate to the “Test” section, select the test_fullSystem environment, and click “Run.”

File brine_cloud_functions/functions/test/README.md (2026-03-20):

# Testing Guide

## Running Tests

To run the tests for the Firebase Functions:

```bash
# Install dependencies (if not already installed)
npm install

# Run all tests
npm test

# Run tests in watch mode (re-runs tests when files change)
npm run test:watch

# Run tests with coverage report
npm test -- --coverage

# Run specific test suites
npm run test:addDevice      # Run addDeviceToUser tests only
npm run test:addFcmToken    # Run addFcmToken tests only
npm run test:addLead        # Run addLead tests only
npm run test:createUser     # Run createUser tests only
npm run test:deleteUser     # Run deleteUser tests only
npm run test:generatePSK    # Run generatePSK tests only
npm run test:getDevice      # Run getDevice tests only
npm run test:getUserDevices # Run getUserDevices tests only
```

## Test Structure

- `addDeviceToUser.test.cjs` - Comprehensive tests for the addDeviceToUser function
- `addFcmToken.test.cjs` - Comprehensive tests for the addFcmToken function
- `addLead.test.cjs` - Comprehensive tests for the addLead function
- `createUser.test.cjs` - Comprehensive tests for the createUser function
- `deleteUser.test.cjs` - Comprehensive tests for the deleteUser function
- `generatePSK.test.cjs` - Comprehensive tests for the generatePSK function
- `getDevice.test.cjs` - Comprehensive tests for the getDevice function
- `getUserDevices.test.cjs` - Comprehensive tests for the getUserDevices function
- `setup.cjs` - Global Jest configuration and mocks

## Test Coverage

### addDeviceToUser Tests
The tests cover:
- Input validation (missing/invalid parameters)
- User document handling (existence, retrieval errors)
- Device addition to user's device list
- Device document creation in devices collection
- Error handling for all Firestore operations
- Edge cases (null/undefined arrays, existing devices)

### addFcmToken Tests
The tests cover:
- Input validation (missing/invalid FCM tokens)
- User document handling (existence, retrieval errors)
- FCM token array management and updates
- Duplicate token prevention
- Error handling for all Firestore operations
- Edge cases (null/undefined token arrays)

### addLead Tests
The tests cover:
- Input validation (missing/invalid name and email parameters)
- Lead document creation with proper structure and timestamps
- Error handling for Firestore document creation failures
- Edge cases (special characters, whitespace handling)
- Firestore integration and collection access validation

### createUser Tests
The tests cover:
- User document creation with proper structure and field initialization
- Authentication context handling and UID extraction
- Error handling for Firestore document creation failures
- Edge cases (long UIDs, special characters in UIDs)
- Firestore integration and database operation validation
- Document structure validation and field type verification

### deleteUser Tests
The tests cover:
- User document deletion with existence checking
- Document existence validation and handling of non-existent documents
- Authentication context handling and UID extraction
- Error handling for Firestore document retrieval and deletion failures
- Edge cases (long UIDs, special characters in UIDs)
- Firestore integration and database operation sequence validation

### generatePSK Tests
The tests cover:
- HTTP method validation (POST only acceptance)
- Input validation (deviceId parameter validation)
- Cryptographically secure PSK generation using crypto.randomBytes
- Firestore storage with proper document structure and metadata
- Error handling for database storage failures
- Edge cases (long device IDs, special characters in device IDs)
- Security validation (proper key length, encoding, and format)
- Response formatting and JSON structure validation

### getDevice Tests
The tests cover:
- Input validation (deviceId query parameter validation)
- User authentication and document existence validation
- Device document retrieval from Firestore
- Access control and authorization (user must own device)
- Error handling for database retrieval failures
- Edge cases (null/undefined device arrays, long device IDs)
- Response formatting and JSON structure validation
- Firestore integration and operation sequence validation

### getUserDevices Tests
The tests cover:
- User authentication and document existence validation
- Device list retrieval and processing from user's device array
- Device detail fetching with filtering of non-existent devices
- Error handling for database retrieval failures
- Edge cases (null/undefined device arrays, large device lists)
- Response formatting and JSON structure validation
- Firestore integration and operation sequence validation
- Performance scenarios with multiple device retrievals

## Mocking Strategy

The tests use Jest mocks to:
- Mock Firebase Admin SDK and Firestore operations
- Mock console methods to reduce test output noise
- Mock Date objects for predictable timestamps (where needed)
- Isolate the functions under test from external dependencies
- Provide comprehensive coverage of all code paths and error scenarios

## Documentation Standards

All test files follow comprehensive documentation standards including:
- Detailed JSDoc comments for all test functions and mock objects
- Clear explanations of test scenarios and expected behaviors
- Comprehensive coverage of edge cases and error conditions
- Integration testing validation for database operations

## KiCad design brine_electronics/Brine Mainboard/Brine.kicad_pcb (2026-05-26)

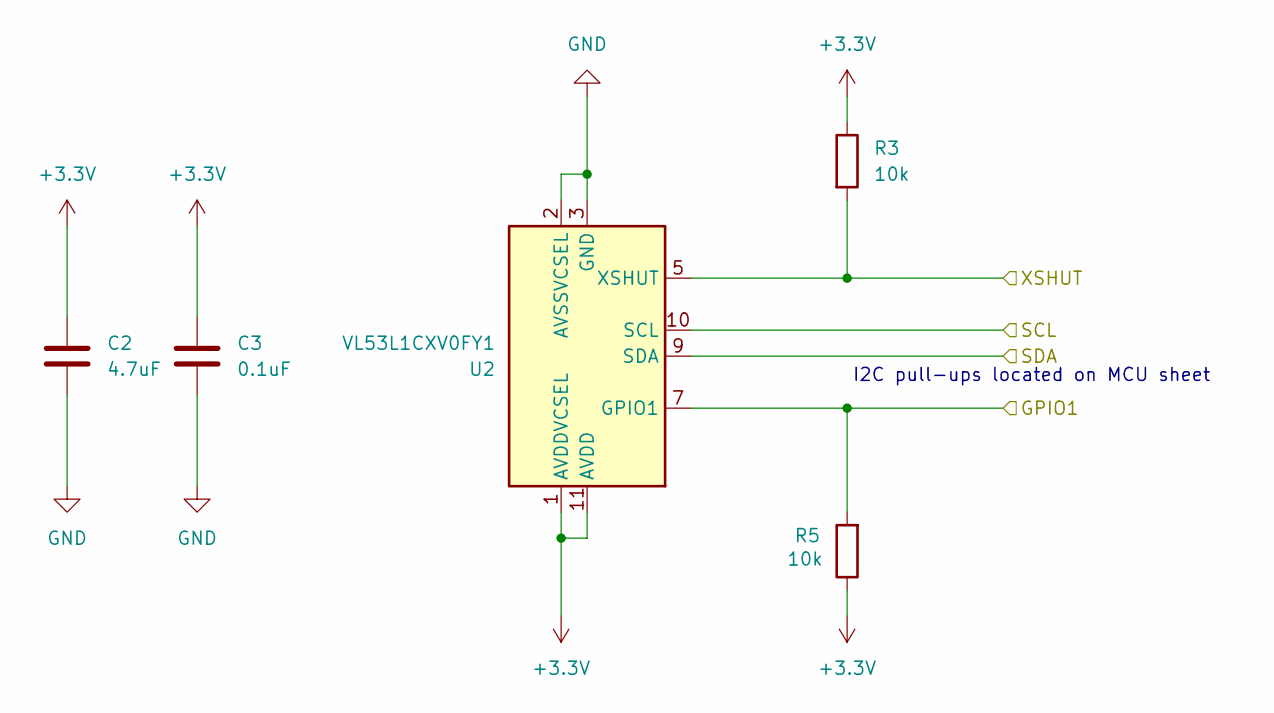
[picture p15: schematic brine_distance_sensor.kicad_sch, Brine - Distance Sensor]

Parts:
C2: 4.7uF; C_0805_2012Metric; LCSC Part # C1746
C3: 0.1uF; C_0805_2012Metric; LCSC Part # C1711
R3, R5: 10k; R_0805_2012Metric; LCSC Part # C17414
U2: VL53L1CXV0FY1; LCSC Part # C190004

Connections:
+3.3V: C2.1, C3.1, R3.1, R5.1, U2.1 (AVDDVCSEL), U2.11 (AVDD); also elsewhere on the board
/Distance Sensor/GPIO1: R5.2, U2.7 (GPIO1); also elsewhere on the board
/Distance Sensor/SCL: U2.10 (SCL); also elsewhere on the board
/Distance Sensor/SDA: U2.9 (SDA); also elsewhere on the board
/Distance Sensor/XSHUT: R3.2, U2.5 (XSHUT); also elsewhere on the board
GND: C2.2, C3.2, U2.2 (AVSSVCSEL), U2.3 (GND), U2.4 (GND), U2.6 (GND), U2.12 (GND); also elsewhere on the board

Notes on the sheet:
I2C pull-ups located on MCU sheet

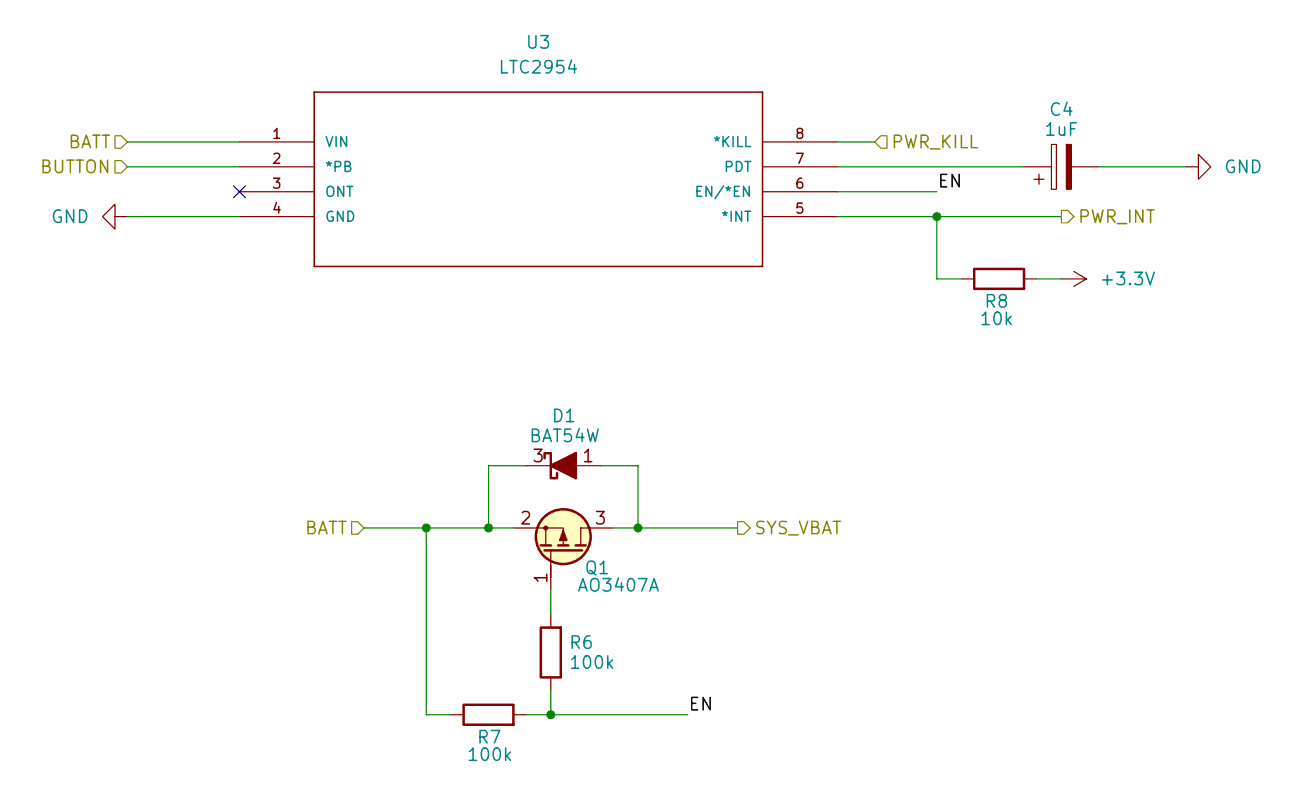
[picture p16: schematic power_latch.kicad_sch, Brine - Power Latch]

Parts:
C4: 1uF; CP_EIA-2012-12_Kemet-R; LCSC Part # C1952822
D1: BAT54W; SOT-323_SC-70; LCSC Part # C8657
Q1: AO3407A; SOT-23; LCSC Part # C347478
R6, R7: 100k; R_0805_2012Metric; LCSC Part # C25611
R8: 10k; R_0805_2012Metric; LCSC Part # C17414
U3: LTC2954; TSOT-23_TS8; MANUFACTURER_PART_NUMBER ltc2954cts81; LCSC Part # C580656

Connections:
+3.3V: R8.2; also elsewhere on the board
/Battery Monitor/SYS_VBAT: D1.1 (A), Q1.3 (D); also elsewhere on the board
/Battery/BATT: D1.3 (K), Q1.2 (S), R7.1, U3.1 (VIN); also elsewhere on the board
/Button/BUTTON: U3.2 (*PB); also elsewhere on the board
/Power Latch/EN: R6.1, R7.2, U3.6 (EN/*EN)
/Power Latch/PWR_INT: R8.1, U3.5 (*INT); also elsewhere on the board
/Power Latch/PWR_KILL: U3.8 (*KILL); also elsewhere on the board
GND: C4.2, U3.4 (GND); also elsewhere on the board
unnamed: Q1.1 (G), R6.2
unnamed: C4.1, U3.7 (PDT)

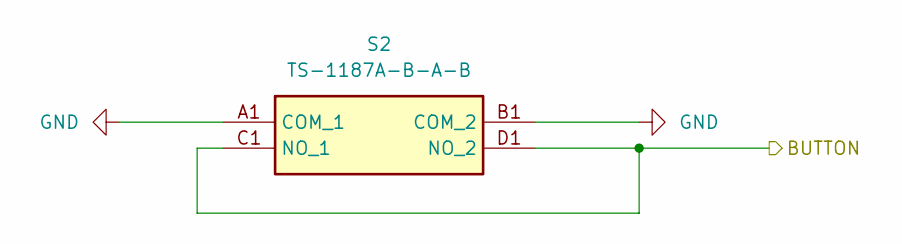
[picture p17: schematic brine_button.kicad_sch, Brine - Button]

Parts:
S2: TS-1187A-B-A-B; TS1187ABAB; LCSC Part # C318884

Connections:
/Button/BUTTON: S2.C1 (NO_1), S2.D1 (NO_2); also elsewhere on the board
GND: S2.A1 (COM_1), S2.B1 (COM_2); also elsewhere on the board

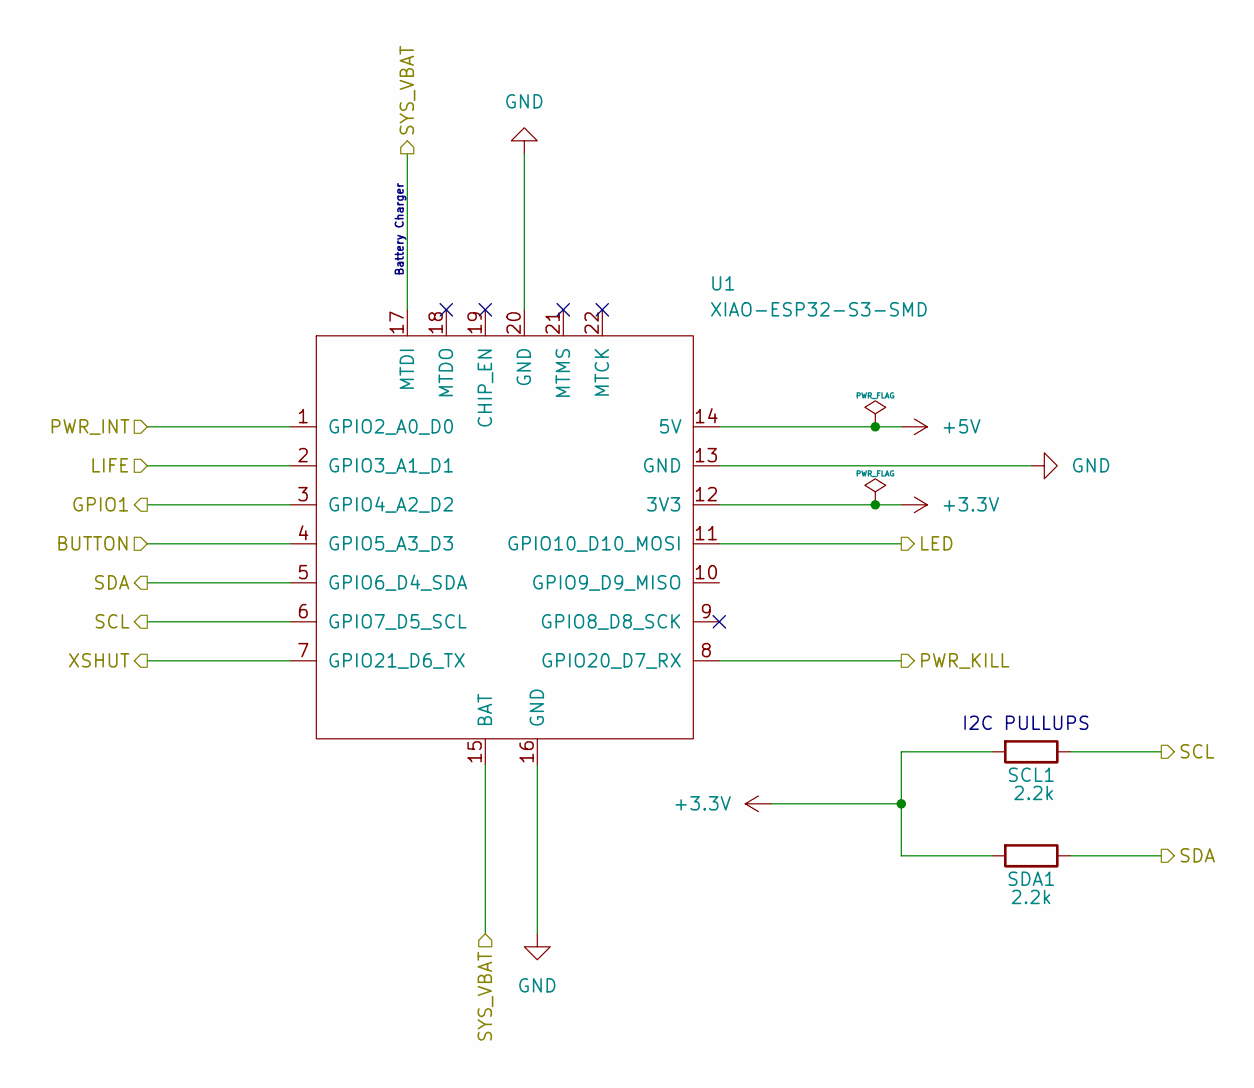
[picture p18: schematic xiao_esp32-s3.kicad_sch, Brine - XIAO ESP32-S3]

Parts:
SCL1: 2.2k; R_0805_2012Metric; LCSC Part # C17520
SDA1: 2.2k; R_0805_2012Metric; LCSC Part # C17520
U1: XIAO-ESP32-S3-SMD; XIAO-ESP32S3-DIP

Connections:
+3.3V: SCL1.2, SDA1.2, U1.12 (3V3); also elsewhere on the board
+5V: U1.14 (5V); also elsewhere on the board
/Battery Monitor/LIFE: U1.2 (GPIO3_A1_D1); also elsewhere on the board
/Button/BUTTON: U1.4 (GPIO5_A3_D3); also elsewhere on the board
/Distance Sensor/GPIO1: U1.3 (GPIO4_A2_D2); also elsewhere on the board
/Distance Sensor/SCL: SCL1.1, U1.6 (GPIO7_D5_SCL); also elsewhere on the board
/Distance Sensor/SDA: SDA1.1, U1.5 (GPIO6_D4_SDA); also elsewhere on the board
/Distance Sensor/XSHUT: U1.7 (GPIO21_D6_TX); also elsewhere on the board
/Power Latch/PWR_INT: U1.1 (GPIO2_A0_D0); also elsewhere on the board
/Power Latch/PWR_KILL: U1.8 (GPIO20_D7_RX); also elsewhere on the board
/RGB LED/LED: U1.11 (GPIO10_D10_MOSI); also elsewhere on the board
GND: U1.13 (GND), U1.16 (GND), U1.20 (GND); also elsewhere on the board

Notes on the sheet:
I2C PULLUPS
Battery Charger

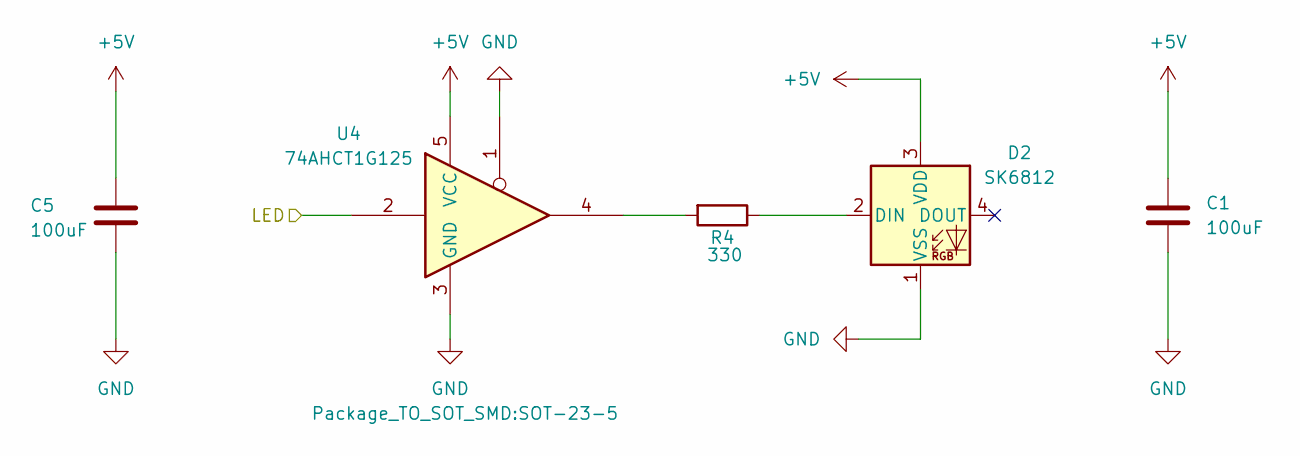
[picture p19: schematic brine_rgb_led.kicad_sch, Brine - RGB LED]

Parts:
C1, C5: 100uF; C_0805_2012Metric; LCSC Part # C141660
D2: SK6812; LED_SK6812_PLCC4_5.0x5.0mm_P3.2mm; LCSC Part # C5378720
R4: 330; R_0805_2012Metric; LCSC Part # C212379
U4: 74AHCT1G125; SOT-23-5; LCSC Part # C52140417

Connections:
+5V: C1.1, C5.1, D2.3 (VDD), U4.5 (VCC); also elsewhere on the board
/RGB LED/LED: U4.2; also elsewhere on the board
GND: C1.2, C5.2, D2.1 (VSS), U4.1, U4.3 (GND); also elsewhere on the board
unnamed: D2.2 (DIN), R4.1
unnamed: R4.2, U4.4

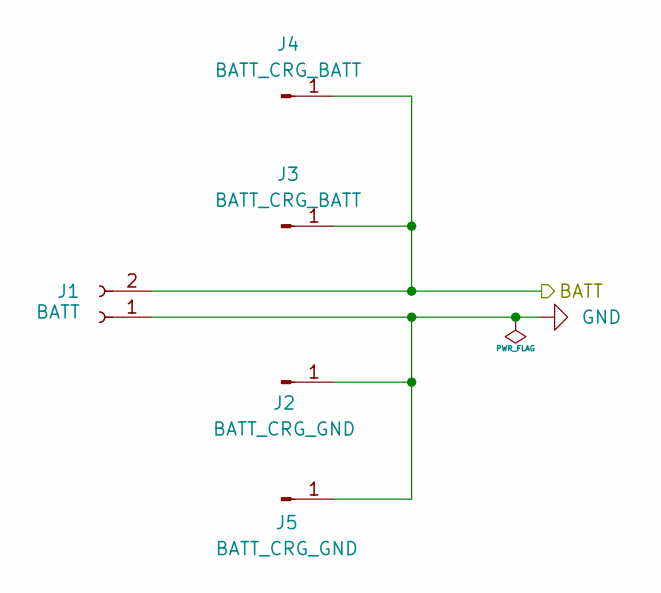
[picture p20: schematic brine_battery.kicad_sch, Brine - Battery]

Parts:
J1: BATT; JST_PH_S2B-PH-K_1x02_P2.00mm_Horizontal
J2: BATT_CRG_GND; SolderWirePad_1x01_SMD_1.5x3mm
J3: BATT_CRG_BATT; SolderWirePad_1x01_SMD_1.5x3mm
J4: BATT_CRG_BATT; PinHeader_1x01_P1.00mm_Vertical
J5: BATT_CRG_GND; PinHeader_1x01_P1.00mm_Vertical

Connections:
/Battery/BATT: J1.2, J3.1 (Pin_1_1), J4.1 (Pin_1_1); also elsewhere on the board
GND: J1.1, J2.1 (Pin_1_1), J5.1 (Pin_1_1); also elsewhere on the board

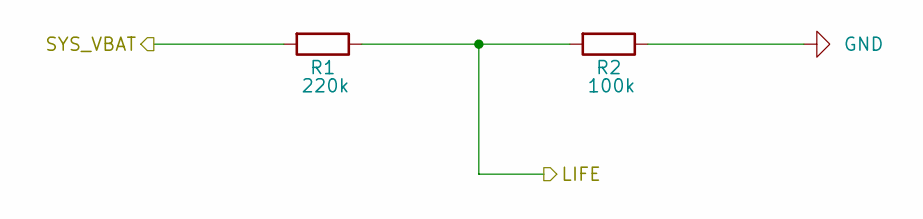
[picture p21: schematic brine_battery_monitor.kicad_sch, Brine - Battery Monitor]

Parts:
R1: 220k; R_0805_2012Metric; LCSC Part # C17556
R2: 100k; R_0805_2012Metric; LCSC Part # C25611

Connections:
/Battery Monitor/LIFE: R1.1, R2.2; also elsewhere on the board
/Battery Monitor/SYS_VBAT: R1.2; also elsewhere on the board
GND: R2.1; also elsewhere on the board

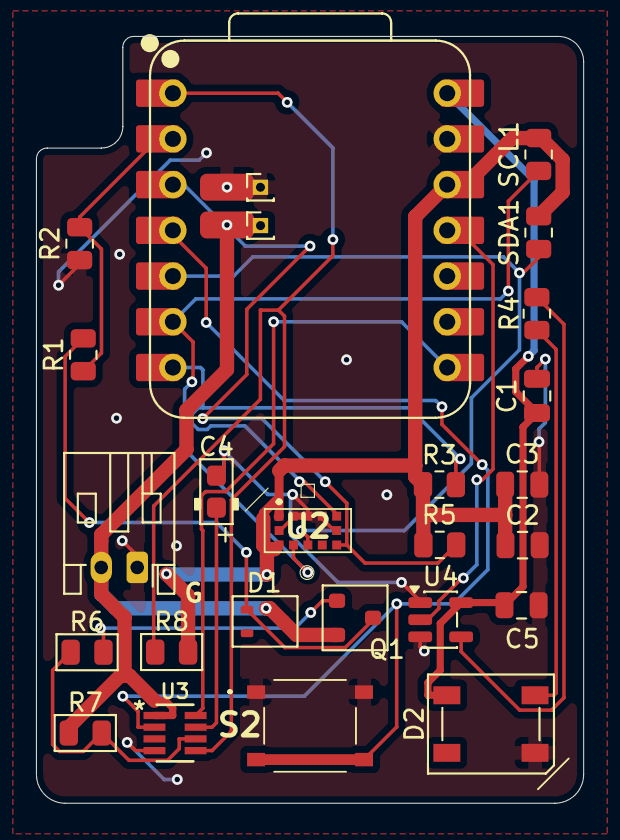
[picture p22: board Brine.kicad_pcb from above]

Board: 2 copper layers, 30.4 x 42.6 mm, 28 parts (0 on the bottom side), 19 nets.

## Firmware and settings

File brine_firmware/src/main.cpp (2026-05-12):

#include <Arduino.h>

#include "DeviceConfig.h"

#include "DebugService.h"
#include <OTAService.h>
#include <BLEApiHandler.h>
#include <BLEModule.h>
#include <BatteryMonitor.h>
#include <DeepSleepService.h>
#include <DeviceConfigurationManager.h>
#include <DistanceSensor.h>
#include <LEDService.h>
#include <PowerLatch.h>
#include <Wire.h>

// Include the appropriate button type based on build configuration
#ifdef GPIO_BUTTON_PIN
#include <GPIOButton.h>
#define BUTTON_TYPE GPIOButton
#else
#include <I2CButton.h>
#define BUTTON_TYPE I2CButton
#endif

/// Button instance used to handle button presses.
BUTTON_TYPE &button = BUTTON_TYPE::getInstance();

/// Power latch service for managing the LTC2954 shutdown circuit.
PowerLatch &powerLatch = PowerLatch::getInstance();

/// Set to true by the PWR_INT interrupt when the user requests a power-off
/// via the LTC2954 pushbutton. Checked cooperatively in the main loop.
volatile bool shutdownRequested = false;

/**
 * @brief ISR for the LTC2954 PWR_INT signal.
 *
 * Invoked on the falling edge of PWR_INT, indicating the user pressed the
 * power button. Sets a flag that the main loop uses to initiate a graceful
 * shutdown sequence.
 */
void IRAM_ATTR powerLatch_isr() { shutdownRequested = true; }

// Tracks whether the I2C button was successfully initialized
bool buttonAvailable = false;

// Determines if the button was pressed. This bool is set to true when the button is pressed and set to false again
// when the provisioning process been running for three minutes or more.
volatile bool buttonPressed = false;

// If the button is held down for this duration, the device will perform a reset.
const unsigned long LONG_PRESS_DURATION = 10000; // 10,000 milliseconds = 10 seconds

// Variables to track button press timing
unsigned long buttonPressStartTime = 0;
bool isLongPressTriggered = false;

// A timestamp for when the provisioning process was started. This is used to create a timeout for the provisioning
// process to prevent it from running indefinitely if no provisioning activities are detected.
unsigned long provisioningStartTime = 0;

// Determines if a client device is connected to the BLE server. While a client is connected, the provisioning process
// should not be interrupted.
bool clientConnected = false;

/**
 * @brief Interrupt service routine for the button.
 *
 * This function is called when the button interrupt is triggered. It sets the `buttonPressed` flag to true.
 *
 * @note This function should be kept as short as possible to prevent blocking the main loop and causing the ESP32 to
 * reset due to a watchdog timeout.
 */
void IRAM_ATTR button_isr() { buttonPressed = true; }

// A handler for Bluetooth API commands and responses.
BLEApiHandler apiHandler;

// Store the BLE characteristic for sending deferred responses
BLECharacteristic *pResponseCharacteristic = nullptr;

// A service for saving and reading values from the non-volatile storage (NVS) of the ESP32.
NVSService &nvsService = NVSService::getInstance();

// A service for sending information to the Firebase cloud backend.
FirebaseService firebaseService;

// A service for getting readings from the distance sensor used to determine the salt level in the water softener based
// on the distance of the salt level from the sensor compared to the overall height of the water softener.
// Sensor type (VL53L0X or VL53L1X) is determined by compile-time configuration.
DistanceSensor sensor;

// A service for handling Over-The-Air (OTA) firmware updates.
OTAService otaService;

/**
 * @brief Checks for available firmware updates and performs the update if available.
 *
 * This function queries the cloud backend to check if a newer firmware version is available.
 * If an update is found, it downloads and applies the update. The device will automatically
 * reboot after a successful update.
 *
 * @return true if an update was performed (device will reboot), false if no update is available or update failed.
 */
bool _checkAndPerformOTAUpdate() {
  DebugService::getInstance().debugPrintln("Checking for firmware updates...");
  DebugService::getInstance().debugPrint("Current firmware version: ");
  DebugService::getInstance().debugPrintln(otaService.getCurrentVersion());

  String latestVersion;
  String downloadUrl;

  // Check if an update is available
  bool updateAvailable = otaService.checkForUpdate(latestVersion, downloadUrl);

  if (updateAvailable) {
    DebugService::getInstance().debugPrintln("Firmware update available: " + latestVersion);
    DebugService::getInstance().debugPrintln("Download URL: " + downloadUrl);

    // Indicate update in progress with LED
    LEDService::getInstance().turnOn();

    // Perform the update
    bool updateSuccess = otaService.performCloudUpdate(downloadUrl);

    if (updateSuccess) {
      // Device will reboot automatically after successful update
      return true;
    } else {
      DebugService::getInstance().debugPrintln("Firmware update failed.");
      LEDService::getInstance().turnOff();
      return false;
    }
  } else {
    DebugService::getInstance().debugPrintln("No firmware update available. Device is up to date.");
    return false;
  }
}

/**
 * @brief Configures the deep sleep management service.
 *
 * This function configures the service that handles the deep sleep cycle for the Brine device. The service handles
 * placing the device into a deep sleep state and setting up the conditions under which it will wake up. When the
 * device wakes, callback functions are invoked.
 * 
 * @param enableTimer If true, enables timer-based wake-up. If false, only button wake-up is enabled.
 */
void _configureDeepSleepService(bool enableTimer = true) {
  DeepSleepService &deepSleepService = DeepSleepService::getInstance();

  // Set the duration to sleep between sensor uploads. In debug mode, this duration is 30 seconds to allow for faster
  // iterations during development. In production, the device waits 24 hours between sensor readings.
  int deepSleepDuration = DebugService::getInstance().DEBUG ? 30000 : 86400000;

  // Configure wake-up sources. The first argument is a duration in milliseconds for the timer wake-up. The second is
  // a GPIO pin used to manually wake up the device.
#ifdef GPIO_BUTTON_PIN
  gpio_num_t wakeupPin = static_cast<gpio_num_t>(GPIO_BUTTON_PIN);
#else
  gpio_num_t wakeupPin = GPIO_NUM_32; // I2C button interrupt pin
#endif
  
  if (enableTimer) {
    deepSleepService.configureWakeUp(deepSleepDuration, wakeupPin);
  } else {
    // Only configure button wake-up, no timer
    deepSleepService.configureWakeUpButtonOnly(wakeupPin);
  }

  // Enter deep sleep.
  deepSleepService.enterDeepSleep();
}

/**
 * @brief Updates the device salt and battery levels in the Firebase cloud.
 *
 * This function retrieves the salt and battery levels from the device's sensors and sends them to the Firebase cloud
 * backend via a POST request. The function uses the `FirebaseService` singleton instance to send the data.
 *
 * @param sleepOnSuccess If true, the device will enter deep sleep after successfully updating the levels.
 *
 * @return true if the data was successfully uploaded to the Firebase cloud, false otherwise.
 */
bool _updateDeviceLevels(bool sleepOnSuccess = false) {
  DebugService::getInstance().debugPrintln("Updating device levels...");

  // Get the "salt level" from the distance sensor.
  float saltLevel = sensor.getDistance();

  // Stop the distance sensor's operations.
  sensor.stopMeasurement();

  // Initialize the battery monitor
  BatteryMonitor batteryMonitor;
  batteryMonitor.begin(Wire);

  // Get the remaining battery life percentage using the BatteryMonitor
  float batteryLife = batteryMonitor.getBatteryLifePercent();

  // Upload the salt and battery levels to the Firebase cloud
  bool success = firebaseService.uploadSensorData(batteryLife, saltLevel);

  if (success) {
    DebugService::getInstance().debugPrintln("Device levels successfully updated in Firebase.");

    // With the device levels updated, the device can now enter deep sleep again.
    if (sleepOnSuccess) {
      _configureDeepSleepService();
    }
  } else {
    DebugService::getInstance().debugPrintln("Failed to update device levels in Firebase.");
  }

  return success;
}

// Function to trigger system reboot
void triggerSystemReboot() {
  DebugService::getInstance().debugPrintln("Long button press detected. Rebooting system...");
  // Perform any necessary cleanup here

  // Clear NVS before rebooting (if desired)
  nvsService.eraseAll();

  // Stop provisioning if it is ongoing.
  provisioningStartTime = 0;

  // Delay to ensure messages are sent before reboot
  delay(1000);

  // Reboot the ESP32
  ESP.restart();
}

/**
 * @brief Connect to the saved WiFi credentials.
 *
 * This function attempts to retrieve the saved WiFi credentials from the NVS service and connect to the WiFi network.
 * If the credentials are not found, it returns a distinct status indicating that retries should be skipped.
 *
 * @return int A status code:
 * - 1 if the device successfully connects to the WiFi network.
 * - 0 if the connection attempt fails.
 * - -1 if no WiFi credentials are found in NVS.
 */
int connectToSavedWiFi() {
  JsonDocument retrievedDoc;

  // Retrieve the JSON document stored under the key "wifiCredentials"
  bool retrieveResult = nvsService.retrieveJSON("wifiCredentials", retrievedDoc);

  if (retrieveResult) {
    DebugService::getInstance().debugPrintln("WiFi credentials retrieved successfully.");

    // Attempt to connect to WiFi using the retrieved credentials.
    WiFi.begin(retrievedDoc["ssid"].as<String>().c_str(), retrievedDoc["password"].as<String>().c_str());

    // Wait for connection with a timeout
    unsigned long startTime = millis();
    const unsigned long timeout = 15000; // 15 seconds timeout

    while (WiFi.status() != WL_CONNECTED && millis() - startTime < timeout) {
      delay(500); // Wait for 500ms before checking again
      DebugService::getInstance().debugPrint(".");
    }

    DebugService::getInstance().debugPrintln(""); // End of dots

    if (WiFi.status() == WL_CONNECTED) {
      DebugService::getInstance().debugPrintln("WiFi connected successfully.");
      DebugService::getInstance().debugPrint("IP Address: ");
      DebugService::getInstance().debugPrintln(WiFi.localIP().toString());
      return 1; // WiFi connected successfully
    } else {
      DebugService::getInstance().debugPrintln("Failed to connect to WiFi within the timeout.");
      return 0; // WiFi connection attempt failed
    }
  } else {
    DebugService::getInstance().debugPrintln("No WiFi credentials found in NVS.");
    return -1; // No WiFi credentials found
  }
}

/**
 * @brief Handles completion of the provisioning process.
 *
 * This function is called when the provisioning process is complete. It returns the Brine device to normal operation.
 */
void onProvisioningComplete() {
  DebugService::getInstance().debugPrintln("Provisioning complete. Stopping provisioning process.");

  // Stop the provisioning process.
  DeviceConfigurationManager::getInstance().stopProvisioning();

  // Turn off the LED in case it was on at the time of the timeout.
  LEDService::getInstance().turnOff();

  // Upload the salt and battery levels to the cloud.
  _updateDeviceLevels(true);
  // TODO handle the upload process failing

  // Reset the provisioning start time and button pressed flags.
  provisioningStartTime = 0;
  buttonPressed = false;
  clientConnected = false;
}

/**
 * @brief Initializes the device configuration manager and sets up Bluetooth callbacks.
 *
 * This function initializes the `DeviceConfigurationManager` singleton instance and sets up the external Bluetooth
 * event callbacks for connection, disconnection, characteristic read, characteristic write, and descriptor write
 * events. These callbacks are used to handle the respective events within the main application logic. After
 * configuring the callbacks, the provisioning process is started by calling the `startProvisioning` method of the
 * `DeviceConfigurationManager` instance.
 *
 * The function also sets the provisioning start time to the current time (in milliseconds), which can be used for
 * timeout management or other time-based operations during the provisioning process.
 *
 * The callbacks are set up as follows:
 *  - Connection callback: Logs a message and handles the connection event.
 *  - Disconnection callback: Logs a message and handles the disconnection event.
 *  - Write callback: Logs the written value and handles the write event.
 *  - Read callback: Logs a message and handles the read event.
 *  - Descriptor write callback: Logs whether notifications have been enabled or disabled and handles the descriptor
 *    write event.
 */
void startProvisioning() {
  // Check for firmware updates at the start of provisioning
  // This ensures the device can be updated even if WiFi credentials are already saved
  int connectStatus = connectToSavedWiFi();
  if (connectStatus == 1) {
    DebugService::getInstance().debugPrintln("WiFi connected. Checking for firmware updates before provisioning...");
    _checkAndPerformOTAUpdate();
    // Disconnect WiFi to save power during provisioning
    WiFi.disconnect();
  }

  // Initialize provisioning manager
  DeviceConfigurationManager &deviceConfigManager = DeviceConfigurationManager::getInstance();

  // Set external callbacks
  deviceConfigManager.setExternalConnectionCallback([](BLEServer *pServer) {
    // Turn on the LED.
    LEDService::getInstance().turnOn();

    // Set the flag to indicate that a client is connected.
    clientConnected = true;
  });

  deviceConfigManager.setExternalDisconnectionCallback([](BLEServer *pServer) {
    // When a client is disconnected, stop the provisioning process early.
    DebugService::getInstance().debugPrintln("Client disconnected. Stopping provisioning process.");

    DeviceConfigurationManager::getInstance().stopProvisioning();

    // Turn off the LED in case it was on at the time of the timeout.
    LEDService::getInstance().turnOff();

    // Reset the provisioning start time and button pressed flags.
    provisioningStartTime = 0;
    buttonPressed = false;
    clientConnected = false;
  });

  // Set the write callback for handling characteristic write events.
  deviceConfigManager.setExternalWriteCallback([&deviceConfigManager](BLECharacteristic *pCharacteristic) {
    std::string value = pCharacteristic->getValue();

    // Store characteristic for deferred responses
    pResponseCharacteristic = pCharacteristic;

    // Parse and queue the command (lightweight - runs in BTC_TASK)
    String immediateResponse = apiHandler.handleCommand(String(value.c_str()));
    
    // Only send response if one was generated (parse errors, unknown commands)
    // Most commands return empty string and will be processed in main loop
    if (immediateResponse.length() > 0) {
      deviceConfigManager.setCharacteristicValue(pCharacteristic, immediateResponse.c_str());
    }
  });

  // Set the read callback for handling characteristic read events.
  deviceConfigManager.setExternalReadCallback([](BLECharacteristic *pCharacteristic) {
    DebugService::getInstance().debugPrintln("Main: Characteristic read");

    // Handle read event in main
  });

  // Set the descriptor write callback for handling descriptor write events.
  deviceConfigManager.setExternalDescriptorWriteCallback([](BLEDescriptor *pDescriptor) {
    uint8_t *data = pDescriptor->getValue();
    if (data[0] == 0x01) {
      DebugService::getInstance().debugPrintln("Main: Notifications enabled");
    } else if (data[0] == 0x00) {
      DebugService::getInstance().debugPrintln("Main: Notifications disabled");
    }
    // Handle descriptor write event in main
  });

  // Start the provisioning process.
  deviceConfigManager.startProvisioning();

  // Set the provisioning start time to the current time.
  provisioningStartTime = millis();
}
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
void loop() {
  // Check if the user requested a power-off via the LTC2954 pushbutton.
  // This is checked first so the device can shut down promptly regardless
  // of what other operations are in progress.
  if (shutdownRequested || powerLatch.isShutdownRequested()) {
    DebugService::getInstance().debugPrintln("Shutdown requested via power button. Beginning graceful shutdown...");

    // Stop provisioning if it is active.
    if (provisioningStartTime != 0) {
      DeviceConfigurationManager::getInstance().stopProvisioning();
    }

    // Turn off the LED.
    LEDService::getInstance().turnOff();

    // Stop the distance sensor if it is running.
    sensor.stopMeasurement();

    // Allow a brief window for any pending serial output to flush.
    delay(100);

    // Assert PWR_KILL to command the LTC2954 to disconnect power.
    powerLatch.shutdown();

    // If power was not cut (latch not populated), reset the flag and continue.
    shutdownRequested = false;
  }

  // Process any pending BLE commands
  if (pResponseCharacteristic != nullptr) {
    String response = apiHandler.processCommand();
    
    if (response.length() > 0) {
      // Check if provisioning is complete
      if (response.indexOf("provisioning_complete") != -1) {
        DeviceConfigurationManager::getInstance().setCharacteristicValue(
          pResponseCharacteristic, 
          response.c_str(), 
          onProvisioningComplete
        );
      } else {
        DeviceConfigurationManager::getInstance().setCharacteristicValue(
          pResponseCharacteristic, 
          response.c_str()
        );
      }
    }
  }

  // Start the provisioning process if the button was pressed and the provisioning process has not already started.
  if (buttonPressed && provisioningStartTime == 0) {
    // Record the time when the button was pressed
    buttonPressStartTime = millis();
    buttonPressed = false; // Reset the flag

    // Start the provisioning process.
    startProvisioning();
  }

  // Check if provisioning is ongoing
  if (provisioningStartTime != 0) {
    // If more than three minutes has passed since the provisioning process started, and a client is not connected,
    // turn off provisioning process.
    if (millis() - provisioningStartTime >= 180000 && !clientConnected) { // 3 minutes
      DebugService::getInstance().debugPrintln("Provisioning process timed out. Turning off provisioning.");

      DeviceConfigurationManager::getInstance().stopProvisioning();

      // Turn off the LED in case it was on at the time of the timeout.
      LEDService::getInstance().turnOff();

      // Reset the provisioning start time and button pressed flags.
      provisioningStartTime = 0;
      buttonPressed = false;

      // Reset the state of the button.
      if (buttonAvailable) {
        button.clearEventBits();
      }

      // Check if the button is currently pressed before going to sleep
      #ifdef GPIO_BUTTON_PIN
      gpio_num_t wakeupPin = static_cast<gpio_num_t>(GPIO_BUTTON_PIN);
      #else
      gpio_num_t wakeupPin = GPIO_NUM_32; // I2C button interrupt pin
      #endif
      
      // Read the current state of the button pin (LOW = pressed with pull-up)
      int buttonState = digitalRead(wakeupPin);
      
      if (buttonState == LOW) {
        DebugService::getInstance().debugPrintln("Button is currently pressed. Waiting for release before sleep...");
        
        // Wait for button to be released (with timeout to prevent infinite loop)
        unsigned long waitStart = millis();
        const unsigned long waitTimeout = 30000; // 30 second timeout
        
        while (digitalRead(wakeupPin) == LOW && (millis() - waitStart < waitTimeout)) {
          delay(100); // Check every 100ms
          LEDService::getInstance().blink(millis()); // Blink to indicate waiting
        }
        
        if (digitalRead(wakeupPin) == LOW) {
          DebugService::getInstance().debugPrintln("Button still pressed after timeout. Entering sleep anyway.");
        } else {
          DebugService::getInstance().debugPrintln("Button released. Safe to enter sleep.");
        }
        
        // Add a small delay to ensure pin has stabilized
        delay(500);
      }

      // Go back to sleep
      // TODO: Check if WiFi is connected to determine if timer should be enabled
      DebugService::getInstance().debugPrintln("Entering deep sleep. Press button to wake and enter provisioning.");
      _configureDeepSleepService();
    } else if (!clientConnected) {
      // Blink LED while provisioning
      LEDService::getInstance().blink(millis());
    }
  }

  // Detect long button press (only if button is available)
  if (buttonAvailable && button.isPressed()) {
    // Check if the duration exceeds the long press threshold
    if (!isLongPressTriggered && (millis() - buttonPressStartTime >= LONG_PRESS_DURATION)) {
      isLongPressTriggered = true;
      triggerSystemReboot();
    }
  } else {
    // Button was released before long press duration
    buttonPressStartTime = 0;
    isLongPressTriggered = false;
  }

  // If the provisioning process is currently running, but a client is not connected yet, blink the LED.
  if (provisioningStartTime != 0 && !clientConnected) {
    LEDService::getInstance().blink(millis());
  }

  // Ensure that the LED is off when provisioning is not running.
  if (provisioningStartTime == 0) {
    LEDService::getInstance().turnOff();
  }
}

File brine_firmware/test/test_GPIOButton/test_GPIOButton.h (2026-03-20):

#ifndef TEST_GPIOBUTTON_H
#define TEST_GPIOBUTTON_H

#include <unity.h>
#include <GPIOButton.h>

/*
 *  This test file tests the GPIOButton class. The GPIOButton class is a singleton class
 * that controls a button connected directly to a GPIO pin. The button should be wired
 * between the GPIO pin and GND, with the internal pull-up resistor providing the HIGH
 * state when the button is not pressed.
 *
 * Hardware Setup:
 * - Connect one side of the button to GPIO8 (or pin specified by GPIO_BUTTON_PIN)
 * - Connect the other side of the button to GND
 * - No external pull-up resistor needed (internal pull-up is used)
 *
 *  Run this test with the command `pio test --filter test_GPIOButton`.
 */

/**
 * @brief Tests initialization of the GPIO button.
 */
void test_gpiobutton_initialization(void) {
  // Test that the button initializes correctly
  TEST_ASSERT_TRUE(GPIOButton::getInstance().begin());
}

/**
 * @brief Tests clearing event bits.
 */
void test_gpiobutton_clear_events(void) {
  // Test that clearing events doesn't cause errors
  GPIOButton::getInstance().clearEventBits();
  
  // Verify button still responds after clearing events
  bool buttonState = GPIOButton::getInstance().isPressed();
  TEST_ASSERT_TRUE(buttonState == true || buttonState == false);
}

/**
 * @brief Tests deep sleep wake-up configuration.
 */
void test_gpiobutton_deep_sleep_wakeup(void) {
  // Test enabling deep sleep wake-up
  bool wakeupResult = GPIOButton::getInstance().enableDeepSleepWakeup(0); // Wake on LOW
  TEST_ASSERT_TRUE(wakeupResult);
  
  // Test with different wake-up level
  wakeupResult = GPIOButton::getInstance().enableDeepSleepWakeup(1); // Wake on HIGH
  TEST_ASSERT_TRUE(wakeupResult);
}

/**
 * @brief Tests getting the button pin number.
 */
void test_gpiobutton_get_pin(void) {
  uint8_t pin = GPIOButton::getInstance().getPin();
  
  // Should return the configured pin (default GPIO8 or build flag override)
  TEST_ASSERT_EQUAL_UINT8(GPIO_BUTTON_PIN, pin);
}

#endif

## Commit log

2022-12-06 Updated app icon :framed_picture:
2022-12-07 Added support for Material dynamic colors :art:
2022-12-25 :hot_pepper: Enabled password-based account creation flow :hot_pepper:
2022-12-26 :motorway: Navigate following successful authentication
2022-12-31 :framed_picture: Updated app icons
2023-04-23 Added function to update battery and salt levels
2023-04-30 Added function to get device levels :salt:
2023-04-30 Added callable function to get device levels
2023-05-03 Updated create account with Google flow :mechanical_arm:
2023-05-05 :film_strip: Added animation to CTA button
2023-06-17 Added function to get a user's devices :mechanical_arm:
2023-06-17 :mechanical_arm: Added setup screen and device(s) retrieval methods
2023-06-26 Overhauled landing page design :art:
2023-06-28 Created landing view for small screen sizes :iphone:
2023-07-02 Removed unused print statement :paw_prints:
2023-07-03 :salt: Added salt and battery level indicators :battery:
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2023-07-04 :point_right: Animate landing CTA button by default :point_left:
2023-07-07 Added social sharing buttons :wave:
2023-07-08 Added Brine device info :brain:
2023-07-10 :pencil2: Updated device info table border
2023-07-16 :package: Submit opt-in form with enter button
2023-07-31 Updated confetti button text :confetti_ball:
2024-02-10 Added battery monitor voltage divider documentation
2024-03-09 Converted device endpoints from callable functions to REST APIs :sleeping_bed:
2024-03-24 Added documentation about the provisioning flow :ocean:
2024-03-27 Created device manager template :building_construction:
2024-03-29 Created button library :zap:
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2024-04-02 Created LED service :bulb:
2024-04-02 Created test for LED service :test_tube:
2024-04-02 Created device management service :salt:
2024-04-03 Updated LED module test :candle:
2024-04-06 Added button test application alembic:
2024-04-06 Split button and LED tests into different suites :card_index_dividers:
2024-04-06 Added distance sensor library :straight_ruler:
2024-04-07 Added test for distance sensor :triangular_ruler:
2024-04-07 Automated LED test :mechanical_arm:
2024-04-07 Updated button Unity test :petri_dish:
2024-04-07 Updated DeviceManager with DistanceSensor interface :straight_ruler:
2024-04-12 Initialize BLE for provisioning on button press :large_blue_circle:
2024-04-19 Blink LED during provisioning :rotating_light:
2024-05-28 Updated image assets reference :camera:
2024-06-01 Fixed issue preventing second provisioning attempt :two:
    [main.cpp, test_I2CButton.cpp]
2024-06-01 Added device confirmation route :+1:
2024-06-01 Added ability to exclude devices :dash:
2024-06-14 Added config file with device ID and script to update it :bust_in_silhouette:
2024-06-15 Get Brine device ID :salt:
2024-06-15 Create device record during association :elephant:
2024-06-15 Send device name with association request :elephant:
2024-06-15 Added battery monitor module :battery:
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2024-06-25 Prevent provisioning timeout while client is connected :sunny:
    [main.cpp]
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2024-10-12 Turn off LED when not in provisioning :bulb:
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2024-12-22 Updated deep sleep duration for debug vs production :bed:
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2025-01-14 Updated system reset process 🐡
    [main.cpp]
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2025-02-08 Added ability to remove devices from account 🚫
2025-02-08 Added function for removing devices from account 🚫
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2025-04-08 Created generic error screen ❗
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2025-04-17 Created error page, updated localizations 💥
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2025-05-12 Added BLE permissions error 🔵
2025-06-24 Updated error page design 🚫
2025-10-08 Created BLE connection error page 🔵
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2025-11-01 Created service and test for GPIO button :point_down:
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2025-11-15 Fixed battery monitor reference 🐛
    [main.cpp]
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2025-11-27 Replaced deprecated API calls ✨
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2025-11-28 Updated device management service for production endpoints 🌐
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2025-11-29 Transfer PSK to Brine device in chunks 🔒
2025-11-29 Defer BLE responses to the main stack 🔵
2025-11-30 Revert "Transfer PSK to Brine device in chunks 🔒"
    This reverts commit e0f4909b53c8fe45753a6efee2a0f0754c76cb96.
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2026-03-20 Add brine_electronics to unified repo
    [Brine BRD v89.brd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]
2026-03-20 Add brine_logos to unified repo
    [Brine_logo.dxf]
2026-03-20 Add .gitignore and remove archived/ignored files from tracking
    [Brine BRD v89.brd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]
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2026-04-03 Archived older PCB designs :package:
    [Brine-B_Cu.gbr, Brine-B_Mask.gbr, Brine-B_Paste.gbr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]
2026-04-03 Created integrated distance sensor
    [Brine.kicad_pcb, Brine.kicad_sch, brine_battery.kicad_sch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]
2026-04-03 Created Gerbers ⚡
    [Brine-B_Cu.gbr, Brine-B_Mask.gbr, Brine-B_Paste.gbr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]
2026-04-05 Updated electronics/enclosure designs
    [Brine-B_Cu.gbr, Brine-B_Mask.gbr, Brine-B_Paste.gbr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]
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2026-04-05 Resolved DRC errors ✅
    [Brine.kicad_pcb]
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2026-04-05 Fixed linter issues ✅
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2026-04-05 Removed unused reference design :wastebasket:
    [Qwiic_Button-Panel.GBL, Qwiic_Button-Panel.GBO, Qwiic_Button-Panel.GBS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]
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2026-04-08 Implemented power latch circuit ⚡
    [Brine.kicad_pcb, Brine.kicad_sch, brine_battery.kicad_sch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]
2026-04-12 Resolved schematic DRC issues ✅
    [Brine.kicad_pcb, Brine.kicad_sch, bom.csv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]
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2026-04-18 Updated PCB manufacturing files :mechanical_arm:
    [Brine.kicad_pcb, bom.csv, brine_rgb_led.kicad_sch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]
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2026-05-04 Updated lower latch circuit ⚡
    [Brine.kicad_pcb, Brine.kicad_sch, brine_battery.kicad_sch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]
2026-05-04 Updated Platform IO configuration to XIAO ESP32-C3 :tropical_fish:
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2026-05-05 Updated button wiring :bug:
    [Brine.kicad_pcb, brine_button.kicad_sch, power_latch.kicad_sch]
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2026-05-07 Updated GPIO button wiring ⚡
    [Brine.kicad_pcb, xiao_esp32-s3.kicad_sch]
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2026-05-16 Fixed linter issues 🐟
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2026-05-17 Fixed linter issues 👖
2026-05-20 Updated distance sensor routing 📏
    [Brine.kicad_pcb, brine_distance_sensor.kicad_sch]
2026-05-26 Updated production files 🏭
    [Brine.kicad_pcb, bom.csv, brine_battery.kicad_sch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]
2026-05-26 Updated electronics production files 🏭
    [brine_battery.kicad_sch, brine_battery_monitor.kicad_sch, brine_button.kicad_sch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]
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
